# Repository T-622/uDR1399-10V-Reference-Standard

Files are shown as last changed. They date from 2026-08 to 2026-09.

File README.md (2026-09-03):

# uDR1399-10V-Reference-Standard

The second revision of the ADR1399 portable bench standard for stable voltage outputs. 

# **Background:**

After the previous version of my ADR1399 standard, the stability left something to be desired. As a result, this version incorporates bootstrapping, an output transistor, and adjustable current limiting. Furthermore, additional ESD protection has been added to the output. The output now incorporates an LT5400 resistor network for gain setting, and as such, is expected to be very stable for the precision gain stage. Two resistors can be used to increase or decrease the gain; although I was not fully after +10.00000V, and wished to have a stable reference first.

Trimming will always be required, as all ADR1399 samples I have recieved in recent times are not close to 7.05V, and usually 6.90V or 6.93V. Care must be taken to use as low temperature coeffecient resistors as possible for trimming, as they introduce extra instabilities to the gain stage.

# **Design:**

## **Schematic**
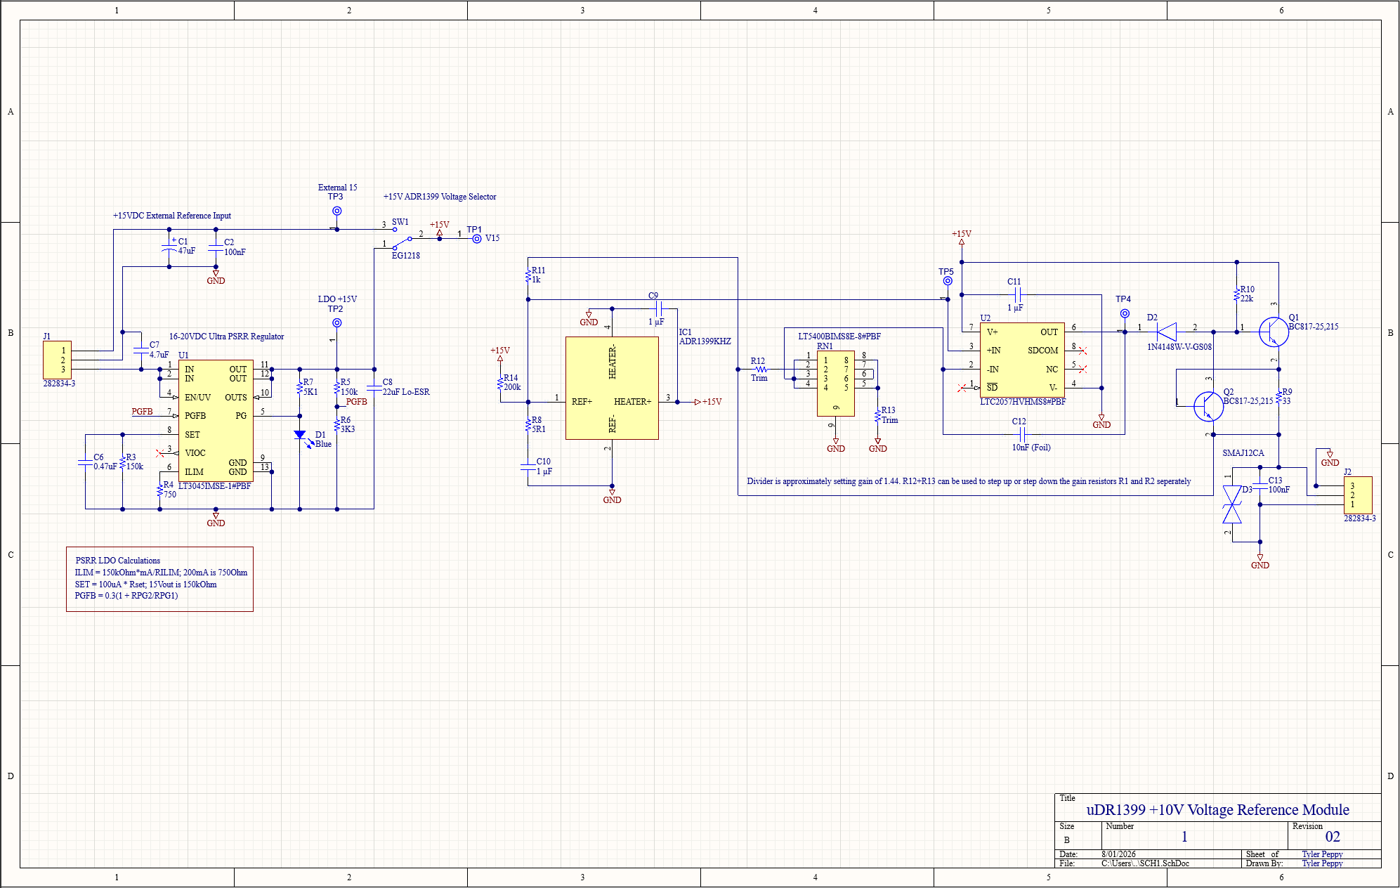
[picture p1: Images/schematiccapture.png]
DesignSchematic


## **Board Layout**

### **2D Board Multilayer:**
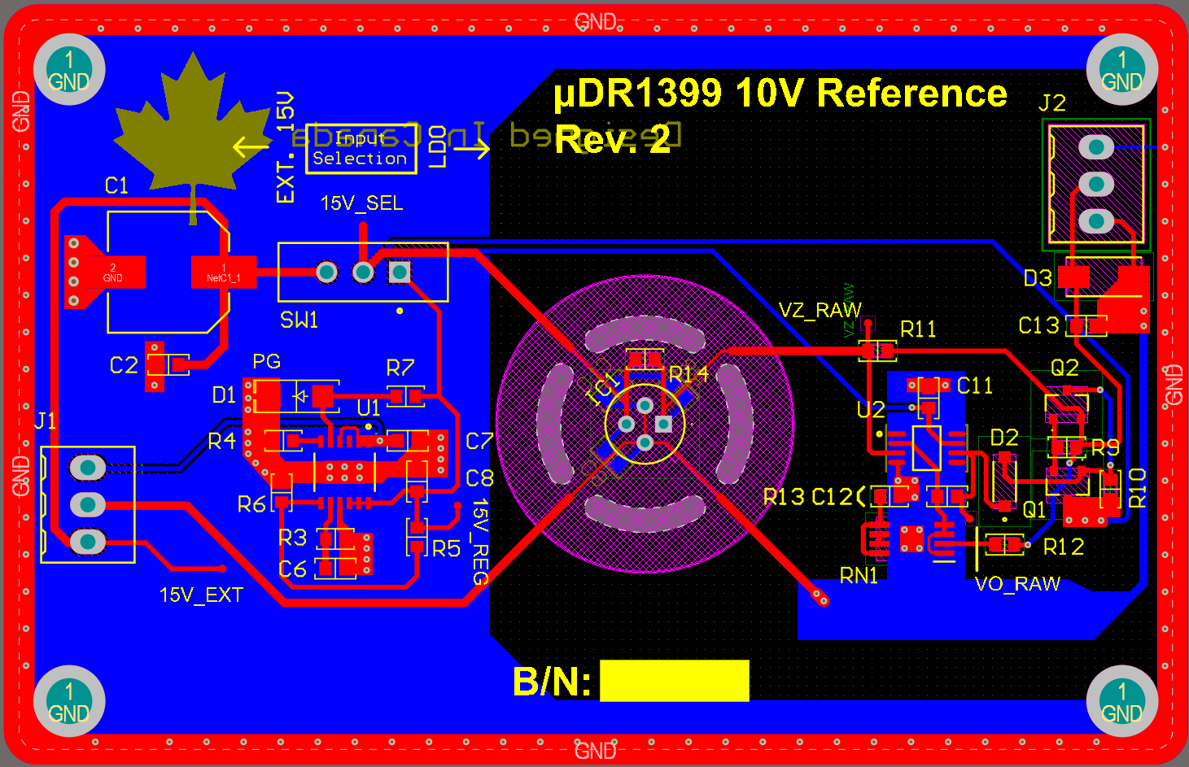
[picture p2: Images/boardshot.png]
Board Layout


### **3D Board Renderings**
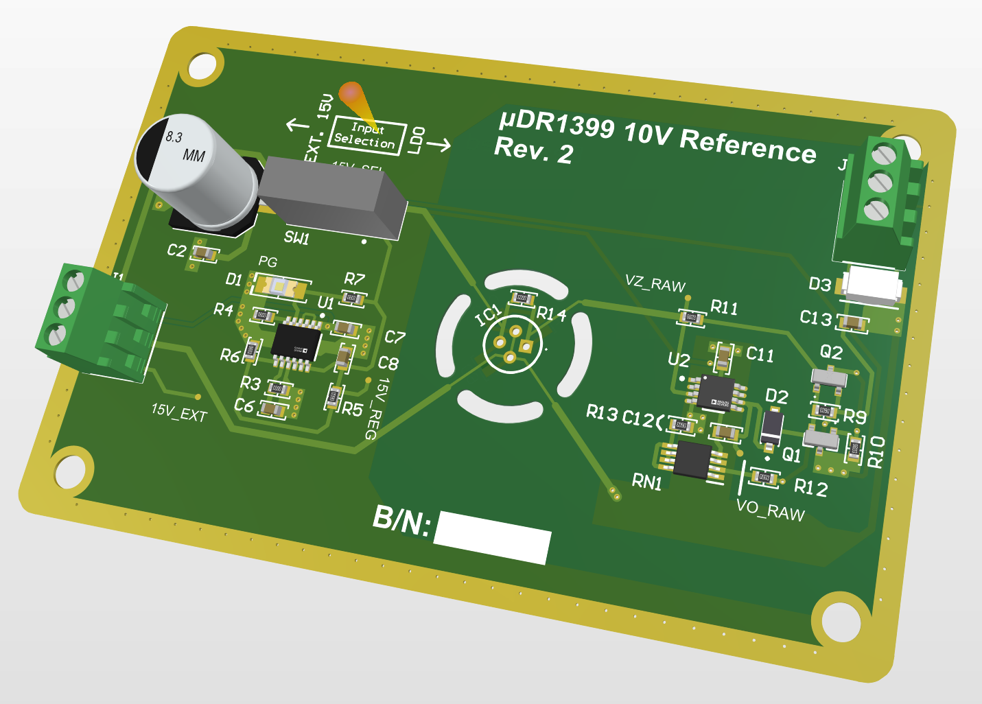
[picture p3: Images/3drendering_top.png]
3D Board Rendering

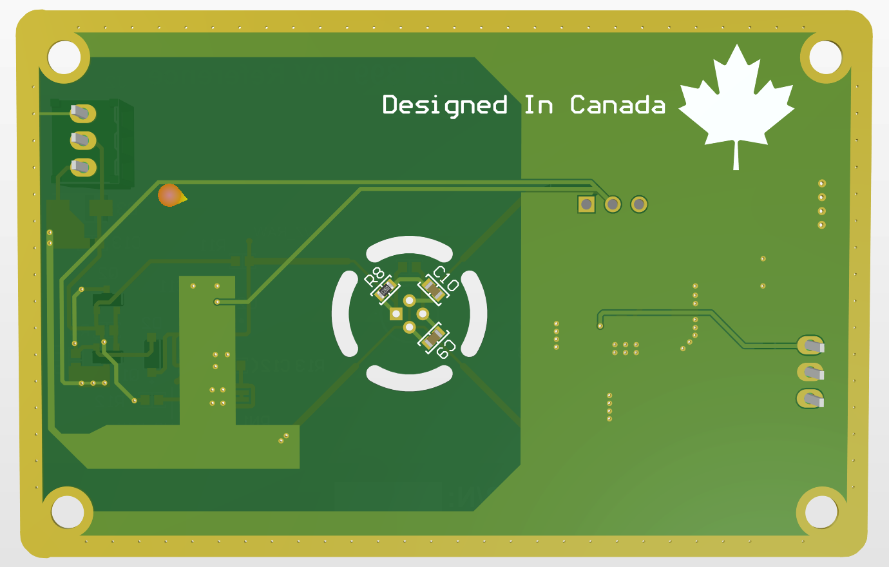
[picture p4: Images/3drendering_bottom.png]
3D Board Rendering


# **Design Notes:**
## **1 - Power Supply:**
Much has stayed from the previous design's power supply (See: [uDR1399 Rev01](https://github.com/T-622/ADR1399-10V-Bench-Standard/tree/main)). The LT3045 is a very good regulator when used properly. One issue I encountered often with the design is that hotplugging power supplies at ~18V with the L, C, and R of the power cables can cause transients large enough to exceed the absolute +22V maximum for the LT3045's inputs. This issue can be resolved through a soft-start circuit using an RC circuit to charge the gate of a p-channel FET, or an appropriate TVS diode. I have not placed these in the design, as my power supply ramps without ringing, and 2x 9V batteries seem to work reasonably well. 

The board's manual power mux is located in the top left corner, and can select from an external 15V regulated supply, or an unregulated 16-20V input fed to the LDO. Optionally, you can use an SPDT switch to externally control the mux. The PG indicator will light up whenever the +15V output is ready from the LDO, regardless if it is being used or not.

## **2 - Island Redesign**
The isolation island was redesigned to use 4 points of contact rather than the previous single tongue design. The previous design would droop under very low force, and cause odd voltage drops. The traces now neck down from 20mil to 10mil to reduce the thermal mass coming out of the island.

## **3 - Gain Stage**
The gain stage was redesigned to use the bootstrapped Zener scheme. As a result, the 3mA zener current will be much more stable against supply fluctuations. Lots of examples are available on the EEVBlog forums using this scheme. An additional 200kOhm resistor was used to assist with startup current for the reference as well. It doesn't seem to cause a different output behavior stuffed or not. It may be left off.

Additionally, the non-inverting amplifier gain resistors are now set by an LT5400 resistor network. The match on these for the B grade parts is 0.025%, with a 0.2ppm/c matching coeffecient. These are configured in a 2K + 4.5K stage, for a gain of 1.44v/v. Two additional trim resistors may be used if required.

## **4 - Output**
I added an ESD diode to the output to prevent damage through mishandling. The output consists of a transistor and a current limit. Currently the 33 ohm set resistor provides a maximum of 10mA. The output features the ~10V output, and the chassis ground, and the sense ground. Either can be chosen for experimentation purposes.

# **Assembly:**
Boards were ordered from JLCPCB using the ENIG-RoHS finish for better board flatness, minimising component lead stresses. A solder stencil was also added for more repeatability while assembling the boards, and better temperature control compared to using an iron. 

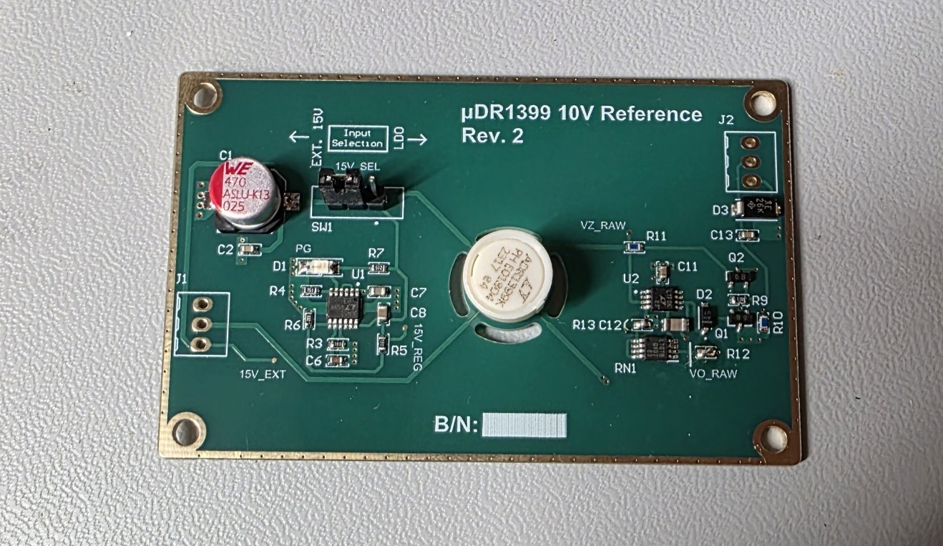
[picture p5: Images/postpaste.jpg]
Assembly


Assembly was done with ChipQuik [SMD291AXT4-T4 Leaded Solder Paste](https://www.digikey.ca/en/products/detail/chip-quik-inc/SMD291AXT4/8543521) and using a cheap hotplate at 235 degrees C. Note that these boards are NOT certified as lead free for obvious reasons. Leaded solder has a lower melting point, and is signficantly better for component stresses according to numerous voltnuts. Bismuth solder paste could be used, but it provides very little mechanical strength.

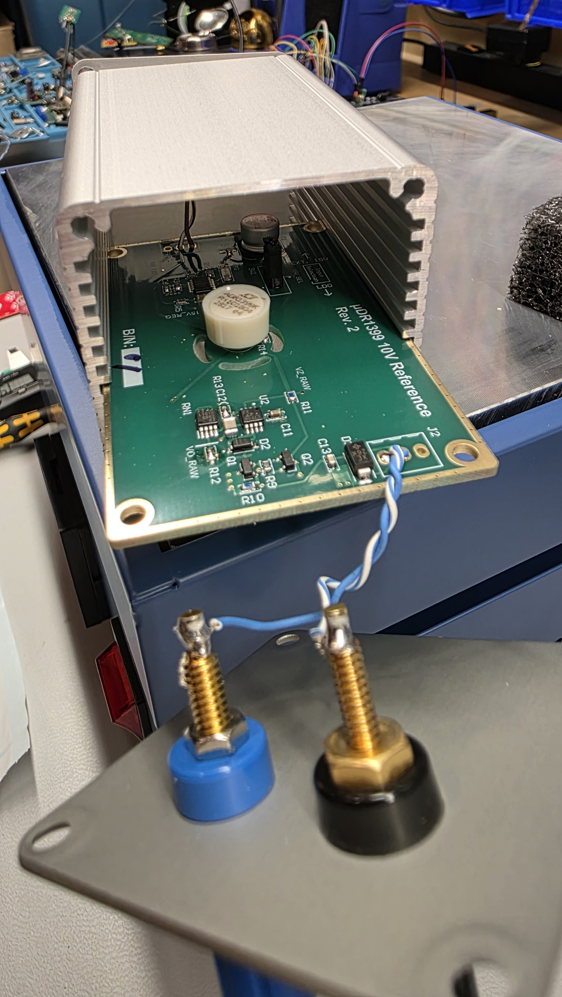
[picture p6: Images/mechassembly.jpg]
Mechanical Case Assembly


The case uses a Hammond Manufacturing 1455CS801 80mmx54mm case with internally ribbed board supports. This is the most simple solution for most users, and uses the top and bottom layer edge plating to ground the enclosure, without directly attaching it to the output sense ground. For binding posts, the output terminals should be assembled with solid copper twisted pair ethernet cable (Cabling can be found for cheap or out of many cables), coupled with Pomona 3770 gold-plated tellurium copper posts.

For output sensing, it is helpful to use 19.05mm spaced posts, as they will fit BNC-Banana for shielded sense leads. The input connectors do not require such posts, and can be used freely. Foam Caps out of closed-cell foam are ideal to attach onto the board to avoid air currents around the ADR1399, but 3D printed ones can be created from the board's .STEP model provided in this repository.

# **Stability Testing**

Before powering ON, PLEASE READ Design Note 1 - Power supply. This will help understanding potential input voltage damage risks associated with connections.

Stability testing was conducted after 72H on unit 1 of 3. The following results were obtained by my Keithley DMM6500 6-1/2 digit multimeter:

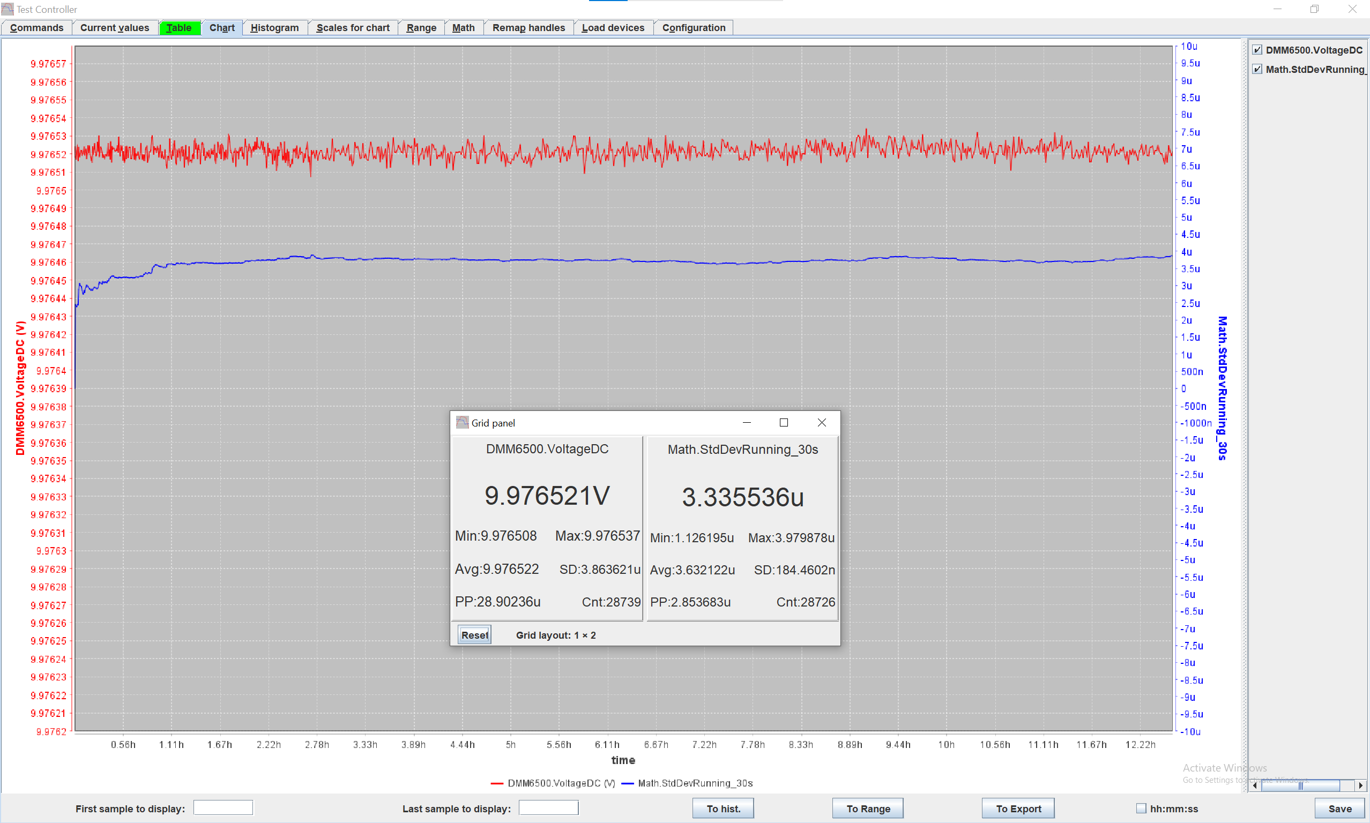
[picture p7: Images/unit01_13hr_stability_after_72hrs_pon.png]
Initial Stability


Using 10NPLC, 10 sample Repeating filter, 10GOhm InZ, AZ On, test controller works well to collect large amounts of stability data. I will update with temeperature data once I get a chance. The DMM6500 is relatively noisy, thus the STD-Dev is calculated over 1799 samples for averaging. 3.33uV STD-Dev is signficantly better than the Rev01 board, which obtained only about 8uV. 

# **Long-Term Stability and Noise Tests**

The unit being tested is approaching 900Hrs of power on / burn in at this point. An MY64 (May 2024 Cal) Keysight 34465A is further being used to aid in stability testing. As in [this](https://www.eevblog.com/forum/testgear/bench-dmm-stability-comparisons-with-testcontroller/125/) extensive thread on the EEVBlog Forums, the Keithley DMM6500 is well suited in being an overall very temperature stable meter with a great interface, but its' internal reference and acquisition mechanism is creating quite a lot of noise. A Keysight 34465A is significantly lower in noise when used in 100PLC to compare to a Keithley's 10PLC + 10x Repeating filter. 

Noise performance was evaluated through 6 tests, split into 100PLC and 10PLC + 10x Smoothing Average filter categories. Each test was averaged over a 5 trial window. Increments of 2min, 5min, and 10min were used to obtain the best representation of the uDR1399's output noise across various time intervals. 

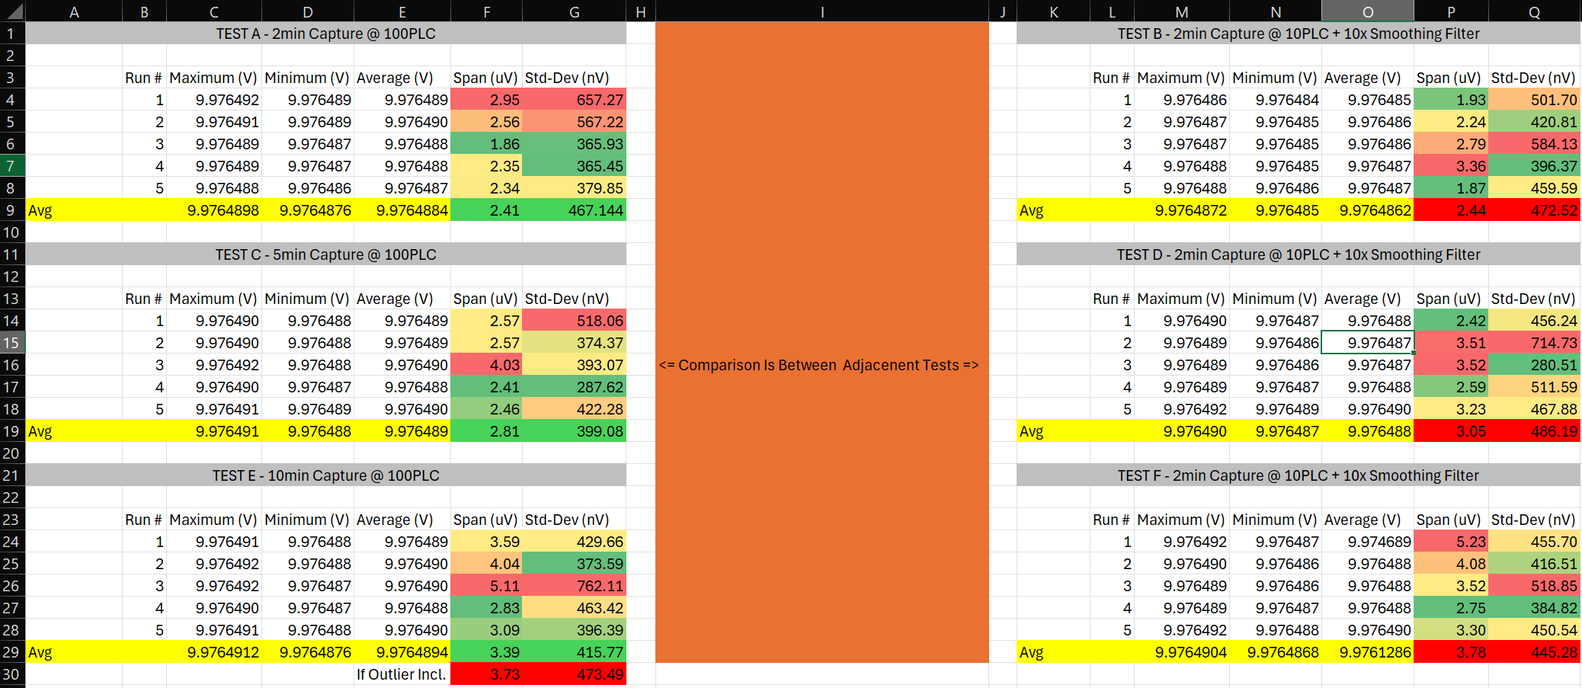
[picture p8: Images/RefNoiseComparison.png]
Reference Noise Comparison Tests


Overall, the uDR1399's output noise appears to be best at 5min sampling @ 100PLC, at approximately 399.08nV. This has been shown on the earlier EEVBlog forum thread to be lower and more temperature-independent than similar modules such as the VREF10. Further testing will be performed on the CircuitValley Ten399 3V1, which utlizes the ADI ADR1399.

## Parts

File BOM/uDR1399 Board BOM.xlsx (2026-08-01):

Country of Origin may be different at time of shipment.
The HTSUS and ECCN information shown is for informational purposes only and is not a representation or warranty as to the accuracy or reliability of these classifications. All information is provided "as is" and is subject to change without notice. Any use made of the information provided is without recourse to Digi-Key and at the user's risk.
Index | Manufacturer Part Number | Manufacturer Name | Description | Lead Time | Availability | Stock Status | Attrition % | Requested Quantity 1 | Pack Quantity 1 | Pack Type 1 | Digi-Key Part Number 1 | Unit Price 1 | Extended Price 1 | Minimum Order Quantity 1 | Requested Quantity 2 | Pack Quantity 2 | Pack Type 2 | Digi-Key Part Number 2 | Unit Price 2 | Extended Price 2 | Minimum Order Quantity 2 | Requested Quantity 3 | Pack Quantity 3 | Pack Type 3 | Digi-Key Part Number 3 | Unit Price 3 | Extended Price 3 | Minimum Order Quantity 3 | Customer Reference | Requested Part Number | Lead Weeks | Datasheet | Reference Designator | US Import Tariff | Note | Part Status | RoHS Status | REACH Status | Moisture Sensitivity Level (MSL) | ECCN | HTSUS | Country of Origin | Environmental Information | Original Part numbers | Unit of Measure | Image | Product Notes
1 | 865090449007 | Würth Elektronik | CAP ALUM 47UF 20% 25V SMD |  | 274 | In Stock |  | 1 | 1 | Cut Tape (CT) | 732-8369-1-ND | 0.76000 | $0.76 | 1 | 1 | 1 | Cut Tape (CT) | 732-8369-1-ND | 0.76000 | $0.76 | 1 | 1 | 1 | Cut Tape (CT) | 732-8369-1-ND | 0.76000 | $0.76 | 1 |  | 732-8369-1-ND | 24 | https://www.we-online.com/components/products/datasheet/865090449007.pdf |  | N/A |  | Active | ROHS3 Compliant | REACH Unaffected | 1 (Unlimited) | EAR99 | 8532.22.0020 | China | https://mm.digikey.com/Volume0/opasdata/d220001/medias/docus/744/Certificate_of_Compliance_ROHS.pdf | 732-8369-1-ND | Each | https://mm.digikey.com/Volume0/opasdata/d220001/derivates/6/002/315/945/MFG_WCAP-ASLU_web%28640x640%29.jpg
2 | C0603C104K5RACTU | KEMET | CAP CER 0.1UF 50V X7R 0603 |  | 6,385,741 | In Stock |  | 2 | 2 | Cut Tape (CT) | 399-C0603C104K5RACTUCT-ND | 0.19000 | $0.38 | 1 | 2 | 2 | Cut Tape (CT) | 399-C0603C104K5RACTUCT-ND | 0.19000 | $0.38 | 1 | 2 | 2 | Cut Tape (CT) | 399-C0603C104K5RACTUCT-ND | 0.19000 | $0.38 | 1 |  | 399-C0603C104K5RACTUCT-ND | 12 | https://yageogroup.com/content/datasheet/asset/file/KEM_C1002_X7R_SMD |  | N/A |  | Active | ROHS3 Compliant | REACH Unaffected | 1 (Unlimited) | EAR99 | 8532.24.0020 | China |  | 399-C0603C104K5RACTUCT-ND | Each | https://mm.digikey.com/Volume0/opasdata/d220001/derivates/6/003/121/213/cut-tape-render_web%28640x640%29.jpg
3 | C1608X5R1C474K080AA | TDK | CAP CER 0.47UF 16V X5R 0603 |  | 32,533 | In Stock |  | 4 | 4 | Cut Tape (CT) | 445-5152-1-ND | 0.15000 | $0.60 | 1 | 1 | 1 | Cut Tape (CT) | 445-5152-1-ND | 0.15000 | $0.15 | 1 | 1 | 1 | Cut Tape (CT) | 445-5152-1-ND | 0.15000 | $0.15 | 1 |  | 445-5152-1-ND | 12 | https://product.tdk.com/system/files/dam/doc/product/capacitor/ceramic/mlcc/catalog/mlcc_commercial_general_en.pdf |  | N/A |  | Active | ROHS3 Compliant | REACH Unaffected | 1 (Unlimited) | EAR99 | 8532.24.0020 | Japan | https://product.tdk.com/system/files/dam/doc/product/capacitor/ceramic/mlcc/rohs/mlccrohs_commercial_general_en.pdf|https://product.tdk.com/en/environment/index.html | 445-5152-1-ND | Each | https://mm.digikey.com/Volume0/opasdata/d220001/derivates/6/002/622/019/C%20Series%200603%281608%20Metric%29%209_web%28640x640%29.jpg
4 | RT0603BRC07150KL | YAGEO | RES SMD 150K OHM 0.1% 1/10W 0603 |  | 4,994 | In Stock |  | 6 | 6 | Cut Tape (CT) | 13-RT0603BRC07150KLCT-ND | 0.43000 | $2.58 | 1 | 2 | 2 | Cut Tape (CT) | 13-RT0603BRC07150KLCT-ND | 0.43000 | $0.86 | 1 | 2 | 2 | Cut Tape (CT) | 13-RT0603BRC07150KLCT-ND | 0.43000 | $0.86 | 1 |  | 13-RT0603BRC07150KLCT-ND | 20 | https://yageogroup.com/content/datasheet/asset/file/PYU-RT_1-TO-0-01_ROHS_L |  | N/A |  | Active | ROHS3 Compliant | REACH Unaffected | 1 (Unlimited) | EAR99 | 8533.21.0030 | Taiwan |  | 13-RT0603BRC07150KLCT-ND | Each | https://mm.digikey.com/Volume0/opasdata/d220001/medias/images/4839/RT-Series-Chip-Resistor.jpg
5 | ERA-3APB751V | Panasonic Industry | RES SMD 750 OHM 0.1% 1/10W 0603 |  | 607 | In Stock |  | 7 | 7 | Cut Tape (CT) | P750AYCT-ND | 0.43000 | $3.01 | 1 | 1 | 1 | Cut Tape (CT) | P750AYCT-ND | 0.43000 | $0.43 | 1 | 1 | 1 | Cut Tape (CT) | P750AYCT-ND | 0.43000 | $0.43 | 1 |  | P750AYCT-ND | 33 | https://industrial.panasonic.com/cdbs/www-data/pdf/RDM0000/AOA0000C307.pdf |  | N/A |  | Active | ROHS3 Compliant | REACH Unaffected | 1 (Unlimited) | EAR99 | 8533.21.0030 | Japan | https://industrial.panasonic.com/cdbs/www-cgi/auto-publishing.cgi?type=ROSU&region=WW&layer=4&cd=AOA0026 | P750AYCT-ND | Each | https://mm.digikey.com/Volume0/opasdata/d220001/medias/images/2391/10-0603%20Resistor.jpg
6 | ERA-3ARW512V | Panasonic Industry | RES SMD 5.1KOHM 0.05% 1/10W 0603 |  | 6,524 | In Stock |  | 8 | 8 | Cut Tape (CT) | P5.1KBECT-ND | 0.79000 | $6.32 | 1 | 1 | 1 | Cut Tape (CT) | P5.1KBECT-ND | 0.79000 | $0.79 | 1 | 1 | 1 | Cut Tape (CT) | P5.1KBECT-ND | 0.79000 | $0.79 | 1 |  | P5.1KBECT-ND | 33 | https://industrial.panasonic.com/cdbs/www-data/pdf/RDM0000/AOA0000C307.pdf |  | N/A |  | Active | ROHS3 Compliant | REACH Unaffected | 1 (Unlimited) | EAR99 | 8533.21.0030 | Japan | https://industrial.panasonic.com/cdbs/www-cgi/auto-publishing.cgi?type=ROSU&region=WW&layer=4&cd=AOA0026 | P5.1KBECT-ND | Each | https://mm.digikey.com/Volume0/opasdata/d220001/medias/images/2391/10-0603%20Resistor.jpg
7 | ERA-3ARB332V | Panasonic Industry | RES SMD 3.3K OHM 0.1% 1/10W 0603 |  | 938 | In Stock |  | 9 | 9 | Cut Tape (CT) | P3.3KBDCT-ND | 0.63000 | $5.67 | 1 | 1 | 1 | Cut Tape (CT) | P3.3KBDCT-ND | 0.63000 | $0.63 | 1 | 1 | 1 | Cut Tape (CT) | P3.3KBDCT-ND | 0.63000 | $0.63 | 1 |  | P3.3KBDCT-ND | 33 | https://industrial.panasonic.com/cdbs/www-data/pdf/RDM0000/AOA0000C307.pdf |  | N/A |  | Active | ROHS3 Compliant | REACH Unaffected | 1 (Unlimited) | EAR99 | 8533.21.0030 | Japan | https://industrial.panasonic.com/cdbs/www-cgi/auto-publishing.cgi?type=ROSU&region=WW&layer=4&cd=AOA0026 | P3.3KBDCT-ND | Each | https://mm.digikey.com/Volume0/opasdata/d220001/medias/images/2391/10-0603%20Resistor.jpg
8 | RG1608N-204-W-T1 | Susumu | RES SMD 200KOHM 0.05% 1/10W 0603 |  | 37,801 | In Stock |  | 10 | 10 | Cut Tape (CT) | RG16N200KWCT-ND | 0.83900 | $8.39 | 1 | 1 | 1 | Cut Tape (CT) | RG16N200KWCT-ND | 1.02000 | $1.02 | 1 | 1 | 1 | Cut Tape (CT) | RG16N200KWCT-ND | 1.02000 | $1.02 | 1 |  | RG16N200KWCT-ND | 22 | https://www.susumu.co.jp/dl/?filename=n_catalog_partition01_en.pdf&type=application/pdf |  | N/A |  | Active | ROHS3 Compliant | REACH Unaffected | 1 (Unlimited) | EAR99 | 8533.21.0030 | Japan | https://www.susumu.co.jp/common/pdf/Certificate%20of%20EU%20RoHS%20compliance.pdf | RG16N200KWCT-ND | Each | https://mm.digikey.com/Volume0/opasdata/d220001/derivates/6/003/243/936/MFG_408_RG_0603_web%28640x640%29.jpg
9 | RNCF0603DTE5R10 | Stackpole Electronics Inc | RES SMD 5.1 OHM 0.5% 1/10W 0603 |  | 4,426 | In Stock |  | 11 | 11 | Cut Tape (CT) | 738-RNCF0603DTE5R10CT-ND | 0.04600 | $0.51 | 1 | 1 | 1 | Cut Tape (CT) | 738-RNCF0603DTE5R10CT-ND | 0.16000 | $0.16 | 1 | 1 | 1 | Cut Tape (CT) | 738-RNCF0603DTE5R10CT-ND | 0.16000 | $0.16 | 1 |  | 738-RNCF0603DTE5R10CT-ND | 18 | https://www.seielect.com/catalog/SEI-RNCF.pdf |  | N/A |  | Active | ROHS3 Compliant | REACH Unaffected | 1 (Unlimited) | EAR99 | 8533.21.0030 | Taiwan | https://www.seielect.com/catalog/SEI-RoHS_Compliance_Status.pdf|https://www.seielect.com/catalog/reach.pdf|https://www.seielect.com/catalog/sei-coc%20prop%2065.pdf | 738-RNCF0603DTE5R10CT-ND | Each | https://mm.digikey.com/Volume0/opasdata/d220001/derivates/6/003/238/576/MFG_RNCF_series_web%28640x640%29.jpg
10 | TNPU060322K0BZEN00 | Vishay Dale | RES SMD 22K OHM 0.1% 1/10W 0603 |  | 1,261 | In Stock |  | 12 | 12 | Cut Tape (CT) | 541-TNPU060322K0BZEN00CT-ND | 2.60300 | $31.24 | 1 | 1 | 1 | Cut Tape (CT) | 541-TNPU060322K0BZEN00CT-ND | 3.14000 | $3.14 | 1 | 1 | 1 | Cut Tape (CT) | 541-TNPU060322K0BZEN00CT-ND | 3.14000 | $3.14 | 1 |  | 541-TNPU060322K0BZEN00CT-ND | 13 | https://www.vishay.com/docs/28779/tnpue3.pdf |  | N/A |  | Active | ROHS3 Compliant | REACH Unaffected | 1 (Unlimited) | EAR99 | 8533.21.0030 | Germany |  | 541-TNPU060322K0BZEN00CT-ND | Each | https://mm.digikey.com/Volume0/opasdata/d220001/medias/images/3648/MFG_TNPU0603.jpg
11 | RT0603BRC0733RL | YAGEO | RES SMD 33 OHM 0.1% 1/10W 0603 |  | 3,048 | In Stock |  | 13 | 13 | Cut Tape (CT) | 13-RT0603BRC0733RLCT-ND | 0.33300 | $4.33 | 1 | 1 | 1 | Cut Tape (CT) | 13-RT0603BRC0733RLCT-ND | 0.40000 | $0.40 | 1 | 1 | 1 | Cut Tape (CT) | 13-RT0603BRC0733RLCT-ND | 0.40000 | $0.40 | 1 |  | 13-RT0603BRC0733RLCT-ND | 20 | https://yageogroup.com/content/datasheet/asset/file/PYU-RT_1-TO-0-01_ROHS_L |  | N/A |  | Active | ROHS3 Compliant | REACH Unaffected | 1 (Unlimited) | EAR99 | 8533.21.0030 | Taiwan |  | 13-RT0603BRC0733RLCT-ND | Each | https://mm.digikey.com/Volume0/opasdata/d220001/medias/images/4839/RT-Series-Chip-Resistor.jpg
12 | TNPU06031K00BZEA00 | Vishay Dale | RES 1 KOHM 0.1% 1/10W 0603 |  | 4,844 | In Stock |  | 14 | 14 | Cut Tape (CT) | 541-4650-1-ND | 1.96600 | $27.52 | 1 | 1 | 1 | Cut Tape (CT) | 541-4650-1-ND | 2.36000 | $2.36 | 1 | 1 | 1 | Cut Tape (CT) | 541-4650-1-ND | 2.36000 | $2.36 | 1 |  | 541-4650-1-ND | 13 | https://www.vishay.com/docs/28779/tnpue3.pdf |  | N/A |  | Active | ROHS3 Compliant | REACH Unaffected | 1 (Unlimited) | EAR99 | 8533.21.0030 | Germany |  | 541-4650-1-ND | Each | https://mm.digikey.com/Volume0/opasdata/d220001/medias/images/3648/MFG_TNPU0603.jpg
13 | CL10A105KO8NNNC | Samsung Electro-Mechanics | CAP CER 1UF 16V X5R 0603 |  | 80,732 | In Stock |  | 15 | 15 | Cut Tape (CT) | 1276-1034-1-ND | 0.06800 | $1.02 | 1 | 3 | 3 | Cut Tape (CT) | 1276-1034-1-ND | 0.16000 | $0.48 | 1 | 3 | 3 | Cut Tape (CT) | 1276-1034-1-ND | 0.16000 | $0.48 | 1 |  | 1276-1034-1-ND | 49 | https://mm.digikey.com/Volume0/opasdata/d220001/medias/docus/609/CL10A105KO8NNNC_Spec.pdf |  | N/A |  | Active | ROHS3 Compliant | REACH Unaffected | 1 (Unlimited) | EAR99 | 8532.24.0020 | Philippines | https://www.samsungsem.com/files/fileDown.do?key=ed1dfdfa-645e-4252-b707-17f9b1502dd1|https://www.samsungsem.com/global/support/certificate/product-stewardship.do | 1276-1034-1-ND | Each | https://mm.digikey.com/Volume0/opasdata/d220001/medias/images/2537/Ceramic-Capacitor-CL-Series.jpg
14 | 1N4148W-E3-08 | Vishay General Semiconductor - Diodes Division | DIODE STANDARD 75V 150MA SOD123 |  | 48,652 | In Stock |  | 17 | 17 | Cut Tape (CT) | 1N4148W-E3-08CT-ND | 0.35300 | $6.00 | 1 | 1 | 1 | Cut Tape (CT) | 1N4148W-E3-08CT-ND | 0.58000 | $0.58 | 1 | 1 | 1 | Cut Tape (CT) | 1N4148W-E3-08CT-ND | 0.58000 | $0.58 | 1 |  | 1N4148W-E3-08CT-ND | 47 | https://www.vishay.com/docs/86356/1n4148w.pdf |  | N/A |  | Active | ROHS3 Compliant | REACH Unaffected | 1 (Unlimited) | EAR99 | 8541.10.0070 | China |  | 1N4148W-E3-08CT-ND | Each | https://mm.digikey.com/Volume0/opasdata/d220001/medias/images/5789/112%7ESOD123%7E%7E2-View-2.jpg
15 | BC817-25 | EVVO | TRANS NPN 45V 0.5A SOT-23 |  | 973 | In Stock |  | 18 | 18 | Cut Tape (CT) | 5272-BC817-25CT-ND | 0.27100 | $4.88 | 1 | 2 | 2 | Cut Tape (CT) | 5272-BC817-25CT-ND | 0.44000 | $0.88 | 1 | 2 | 2 | Cut Tape (CT) | 5272-BC817-25CT-ND | 0.44000 | $0.88 | 1 |  | 5272-BC817-25CT-ND | 3 | https://mm.digikey.com/Volume0/opasdata/d220001/medias/docus/7158/5272_BC817-25.pdf |  | N/A |  | Active | ROHS3 Compliant | REACH Unaffected | 1 (Unlimited) | EAR99 | 8541.21.0075 | China |  | 5272-BC817-25CT-ND | Each | https://mm.digikey.com/Volume0/opasdata/d220001/derivates/6/003/235/272/MFG_5272%7ESOT23-3%7E%7E3_web%28640x640%29.jpg
16 | SMAJ12CA-E3/5A | Vishay General Semiconductor - Diodes Division | TVS DIODE 12VWM 19.9VC DO214AC |  | 4,664 | In Stock |  | 19 | 19 | Cut Tape (CT) | SMAJ12CA-E3/5AGICT-ND | 0.51800 | $9.84 | 1 | 1 | 1 | Cut Tape (CT) | SMAJ12CA-E3/5AGICT-ND | 0.83000 | $0.83 | 1 | 1 | 1 | Cut Tape (CT) | SMAJ12CA-E3/5AGICT-ND | 0.83000 | $0.83 | 1 |  | SMAJ12CA-E3/5AGICT-ND | 28 | https://www.vishay.com/docs/88390/smaj50a.pdf |  | N/A |  | Active | ROHS3 Compliant | REACH Unaffected | 1 (Unlimited) | EAR99 | 8541.10.0080 | Taiwan |  | SMAJ12CA-E3/5AGICT-ND | Each
17 | LT3045IMSE-1#PBF | Analog Devices Inc. | IC REG LIN POS ADJ 500MA 12MSOP |  | 3,196 | In Stock |  | 20 | 20 | Tube | 505-LT3045IMSE-1#PBF-ND | 12.91000 | $258.20 | 1 | 1 | 1 | Tube | 505-LT3045IMSE-1#PBF-ND | 16.55000 | $16.55 | 1 | 1 | 1 | Tube | 505-LT3045IMSE-1#PBF-ND | 16.55000 | $16.55 | 1 |  | 505-LT3045IMSE-1#PBF-ND | 19 | https://www.analog.com/media/en/technical-documentation/data-sheets/30451fa.pdf |  | N/A |  | Active | ROHS3 Compliant | REACH Unaffected | 1 (Unlimited) | EAR99 | 8542.39.0070 | Thailand | https://www.analog.com/media/en/material-declaration/LT3045IMSE-1%23PBF.PDF | 505-LT3045IMSE-1#PBF-ND | Each | https://mm.digikey.com/Volume0/opasdata/d220001/medias/images/4830/505%7E05-08-1666%7EMSE%7E12-Pad-View.JPG
18 | ADR1399KHZ | Analog Devices Inc. | IC VREF SHUNT 7.05V 0.05% TO46-4 |  | 1,263 | In Stock |  | 21 | 21 | Tube | 505-ADR1399KHZ-ND | 32.74350 | $687.61 | 1 | 1 | 1 | Tube | 505-ADR1399KHZ-ND | 42.69000 | $42.69 | 1 | 1 | 1 | Tube | 505-ADR1399KHZ-ND | 42.69000 | $42.69 | 1 |  | 505-ADR1399KHZ-ND | 10 | https://www.analog.com/media/en/technical-documentation/data-sheets/adr1399.pdf |  | N/A |  | Active | ROHS3 Compliant | REACH Unaffected | 1 (Unlimited) | EAR99 | 8542.39.0090 | Philippines |  | 505-ADR1399KHZ-ND | Each | https://mm.digikey.com/Volume0/opasdata/d220001/derivates/6/003/228/004/MFG_505%7E05-08-1341%7EH%7E4_web%28640x640%29.jpg
19 | LT5400BIMS8E-8#PBF | Analog Devices Inc. | RES ARRAY 4 RES MULT OHM 8TSSOP |  | 682 | In Stock |  | 22 | 22 | Tube | LT5400BIMS8E-8#PBF-ND | 17.65700 | $388.45 | 1 | 1 | 1 | Tube | LT5400BIMS8E-8#PBF-ND | 25.16000 | $25.16 | 1 | 1 | 1 | Tube | LT5400BIMS8E-8#PBF-ND | 25.16000 | $25.16 | 1 |  | LT5400BIMS8E-8#PBF-ND | 13 | https://www.analog.com/media/en/technical-documentation/data-sheets/5400fc.pdf |  | N/A |  | Active | ROHS3 Compliant | REACH Unaffected | 1 (Unlimited) | EAR99 | 8533.21.0020 | Thailand | https://www.analog.com/media/en/material-declaration/LT5400BIMS8E-8%23PBF.PDF | LT5400BIMS8E-8#PBF-ND | Each | https://mm.digikey.com/Volume0/opasdata/d220001/derivates/6/001/124/015/505%7E05-08-1662%7EMS8E%7E8_web%28640x640%29.jpg
20 | LTC2057IMS8#PBF | Analog Devices Inc. | IC OPAMP ZERO-DRIFT 1 CIRC 8MSOP |  | 2,254 | In Stock |  | 23 | 23 | Tube | 505-LTC2057IMS8#PBF-ND | 4.97800 | $114.49 | 1 | 1 | 1 | Tube | 505-LTC2057IMS8#PBF-ND | 6.58000 | $6.58 | 1 | 1 | 1 | Tube | 505-LTC2057IMS8#PBF-ND | 6.58000 | $6.58 | 1 |  | 505-LTC2057IMS8#PBF-ND | 19 | https://www.analog.com/media/en/technical-documentation/data-sheets/2057f.pdf |  | N/A |  | Active | ROHS3 Compliant | REACH Unaffected | 1 (Unlimited) | EAR99 | 8542.33.0001 | Thailand | https://www.analog.com/media/en/material-declaration/LTC2057IMS8%23PBF.PDF | 505-LTC2057IMS8#PBF-ND | Each | https://mm.digikey.com/Volume0/opasdata/d220001/derivates/6/300/951/778/505%7E05-08-1660%7EMS8%7E8_web%28640x640%29.jpg
21 | 1455CS801 | Hammond Manufacturing | EXTRUDED ALUMINUM ENCLOSURE W/ M | 20 in stock at manufacturer warehouse as of 31-Jul-2026 | 4 | In Stock |  | 24 | 24 | Bulk | 164-1455CS801-ND | 21.21700 | $509.21 | 1 | 1 | 1 | Bulk | 164-1455CS801-ND | 27.14000 | $27.14 | 1 | 1 | 1 | Bulk | 164-1455CS801-ND | 27.14000 | $27.14 | 1 |  | 164-1455CS801-ND | 8 | https://www.hammfg.com/electronics/small-case/extruded/1455.pdf |  | N/A |  | Active | ROHS3 Compliant | REACH Unaffected | Not Applicable | EAR99 | 7612.90.1090 | Canada |  | 164-1455CS801-ND | Each | https://mm.digikey.com/Volume0/opasdata/d220001/derivates/6/003/232/509/1455CS801_web%28640x640%29.jpg | This product can be customized by the manufacturer.
22 | GMK107BBJ475KA-T | Taiyo Yuden | CAP CER 4.7UF 35V X5R 0603 |  | 26,177 | In Stock |  | 1 | 1 | Cut Tape (CT) | 587-GMK107BBJ475KA-TCT-ND | 0.68000 | $0.68 | 1 |  |  |  |  |  |  |  |  |  |  |  |  |  |  |  | 587-GMK107BBJ475KA-TTR-ND | 13 | https://mm.digikey.com/Volume0/opasdata/d220001/medias/docus/57/GMK107BBJ475KA-T_SS.pdf |  | N/A |  | Active | ROHS3 Compliant | REACH Unaffected | 1 (Unlimited) | EAR99 | 8532.24.0020 | Japan |  | 587-GMK107BBJ475KA-TTR-ND | Each | https://mm.digikey.com/Volume0/opasdata/d220001/medias/images/331/Taiyo-Yuden-0603-%281608-Metric%29.jpg
23 | CL10A226MO7JZNC | Samsung Electro-Mechanics | CAP CER 22UF 16V X5R 0603 |  | 215,193 | In Stock |  | 1 | 1 | Cut Tape (CT) | 1276-7076-1-ND | 1.22000 | $1.22 | 1 |  |  |  |  |  |  |  |  |  |  |  |  |  |  |  | 1276-7076-1-ND | 39 | https://mm.digikey.com/Volume0/opasdata/d220001/medias/docus/2139/CL10A226MO7JZNC_Spec.pdf |  | N/A |  | Active | ROHS3 Compliant | REACH Unaffected | 1 (Unlimited) | EAR99 | 8532.24.0020 | Philippines | https://www.samsungsem.com/files/fileDown.do?key=ed1dfdfa-645e-4252-b707-17f9b1502dd1|https://www.samsungsem.com/global/support/certificate/product-stewardship.do | 1276-7076-1-ND | Each | https://mm.digikey.com/Volume0/opasdata/d220001/medias/images/2537/Ceramic-Capacitor-CL-Series.jpg
24 | 150120BS75000 | Würth Elektronik | LED BLUE CLEAR 1206 SMD |  | 78,614 | In Stock |  | 1 | 1 | Cut Tape (CT) | 732-4989-1-ND | 0.36000 | $0.36 | 1 |  |  |  |  |  |  |  |  |  |  |  |  |  |  |  | 732-4989-1-ND | 13 | https://www.we-online.com/components/products/datasheet/150120BS75000.pdf |  | N/A |  | Active | ROHS3 Compliant | REACH Unaffected | 3 (168 Hours) | EAR99 | 8541.41.0000 | China | https://mm.digikey.com/Volume0/opasdata/d220001/medias/docus/744/Certificate_of_Compliance_ROHS.pdf | 732-4989-1-ND | Each | https://mm.digikey.com/Volume0/opasdata/d220001/medias/images/536/WL-SMCW-SERIES-1206-PKG.jpg
25 | ECH-U1H103JX5 | Panasonic Industry | CAP FILM 10000PF 5% 50VDC 1206 |  | 68,004 | In Stock |  | 1 | 1 | Cut Tape (CT) | PCF1340CT-ND | 0.95000 | $0.95 | 1 |  |  |  |  |  |  |  |  |  |  |  |  |  |  |  | PCF1340CT-ND | 12 | https://industrial.panasonic.com/ww/products/pt/film-cap-electroequip/models/ECHU1H103JX5 |  | N/A |  | Active | ROHS3 Compliant | REACH Unaffected | 1 (Unlimited) | EAR99 | 8532.25.0010 | Japan |  | PCF1340CT-ND | Each | https://mm.digikey.com/Volume0/opasdata/d220001/medias/images/2422/ECH-UB-UX%20SERIES%201206.jpg

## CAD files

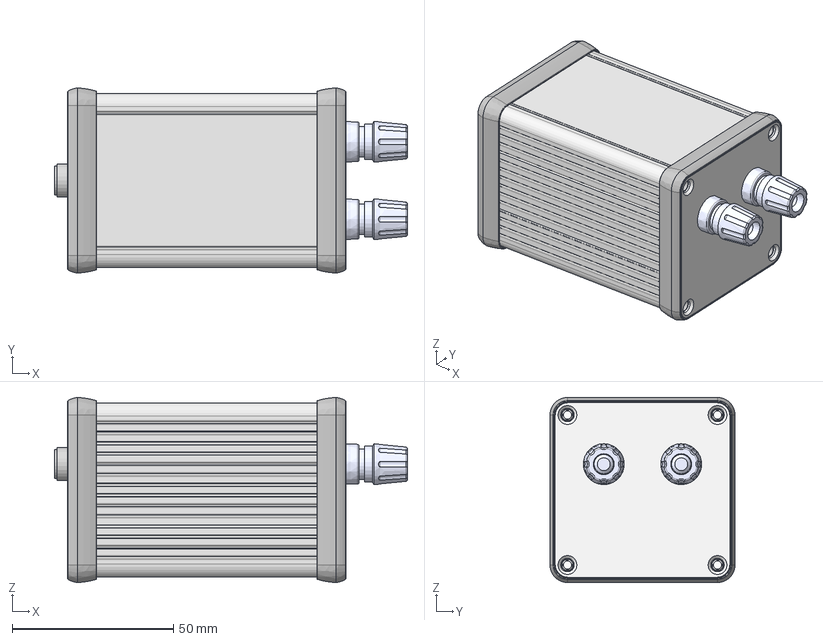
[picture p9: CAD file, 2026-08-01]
Mechanical Items/10V Reference Assembly.step
109.4 x 57.4 x 57.4 mm

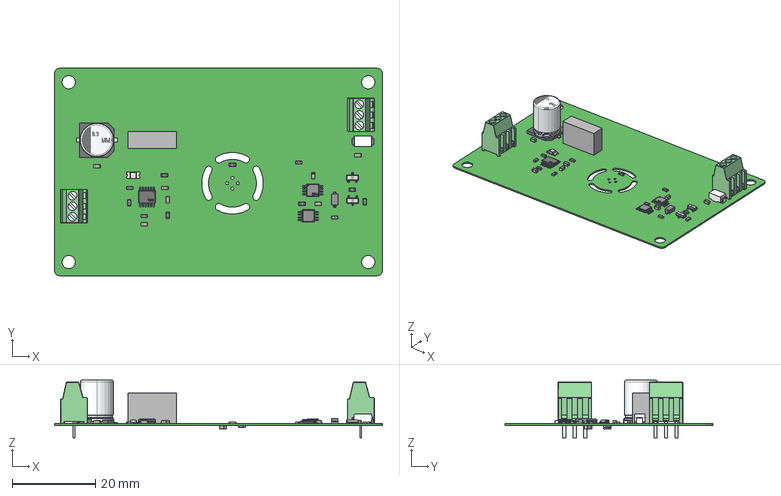
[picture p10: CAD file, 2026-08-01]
Mechanical Items/uDR1399_Board_Model.step
79.0 x 50.0 x 13.9 mm

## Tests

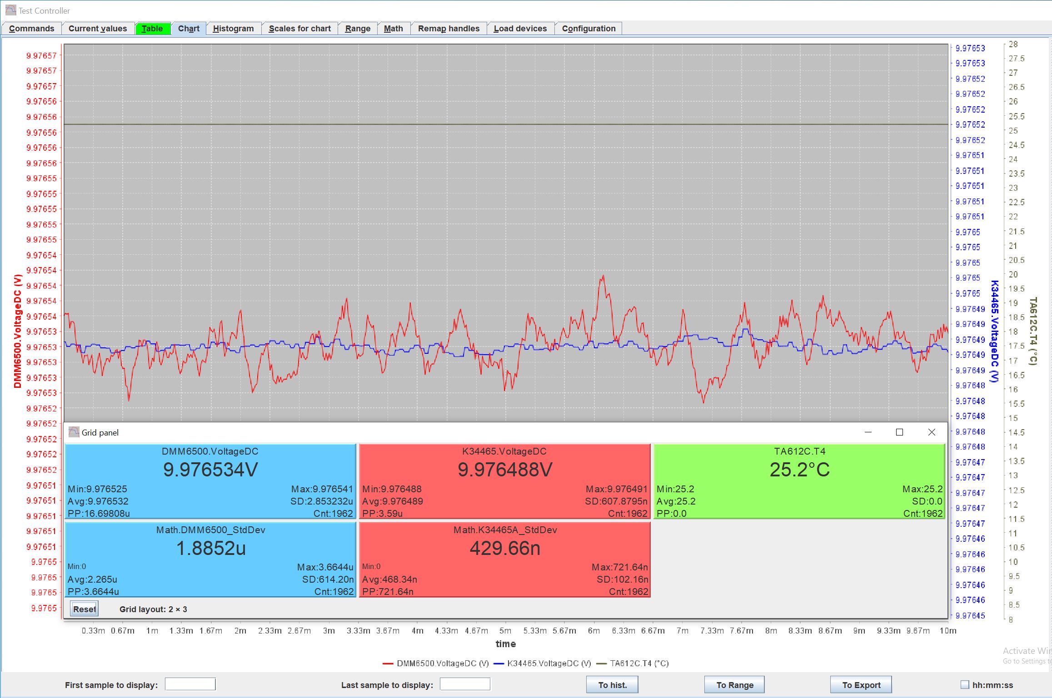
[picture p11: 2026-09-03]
uDR1399 Validation Tests/10min Tests/100PLC/100PLC_01.JPG

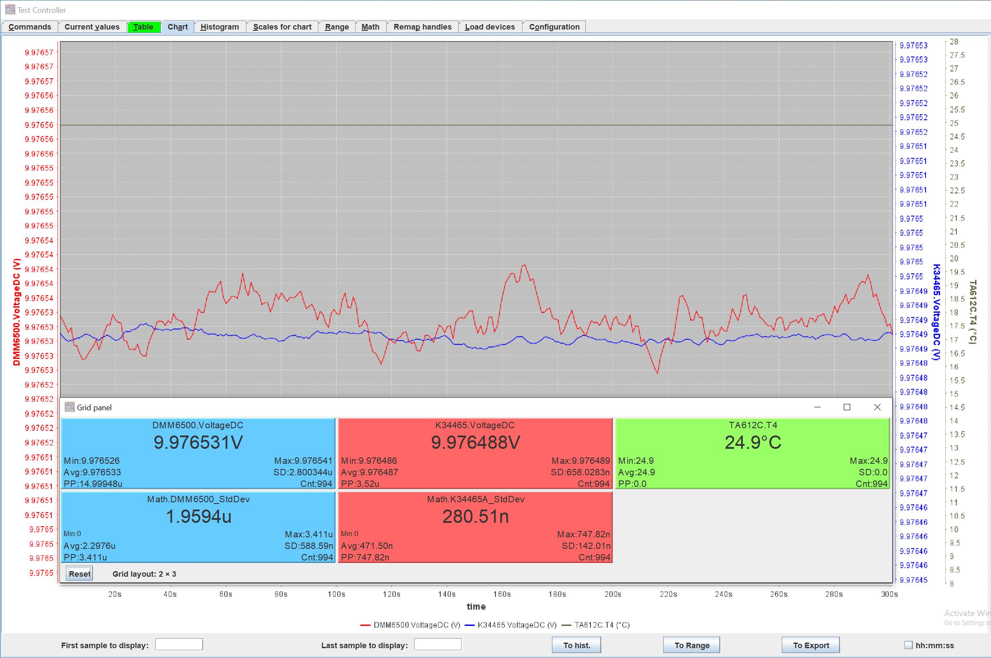
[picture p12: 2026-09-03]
uDR1399 Validation Tests/5min Tests/10PLC + 10x Smoothing/10PLC_With_Filter_03.JPG

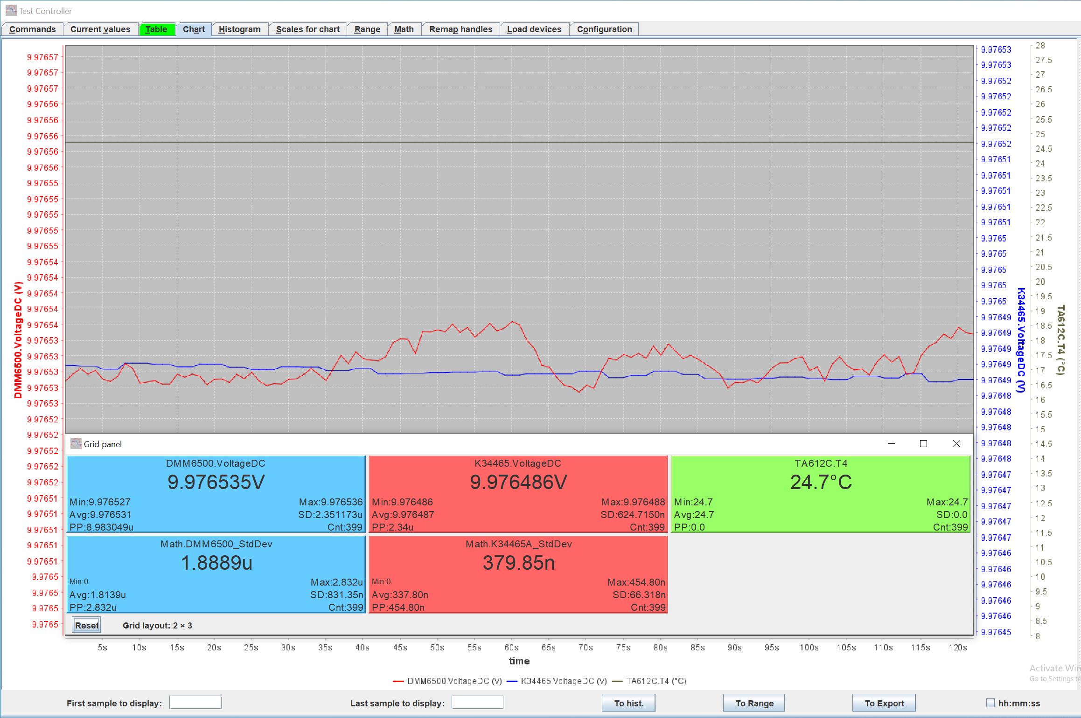
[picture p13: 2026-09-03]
uDR1399 Validation Tests/2min Tests/100PLC/100PLC_05.JPG

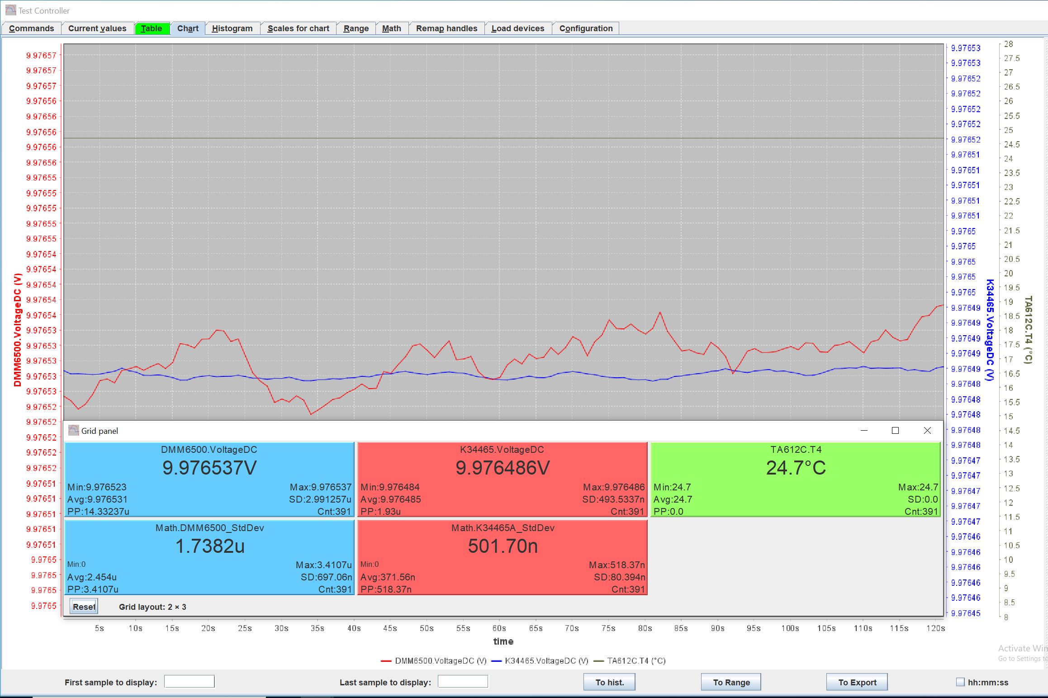
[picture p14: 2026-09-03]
uDR1399 Validation Tests/2min Tests/10PLC + 10x Smoothing/10PLC_With_10xFilter_01.JPG

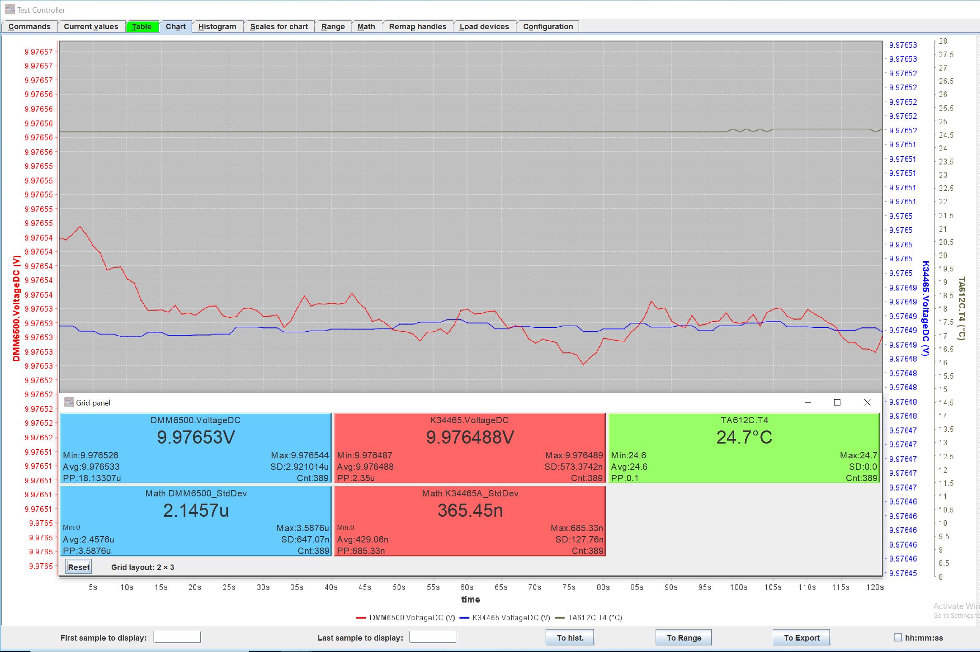
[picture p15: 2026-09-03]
uDR1399 Validation Tests/2min Tests/100PLC/100PLC_04.JPG

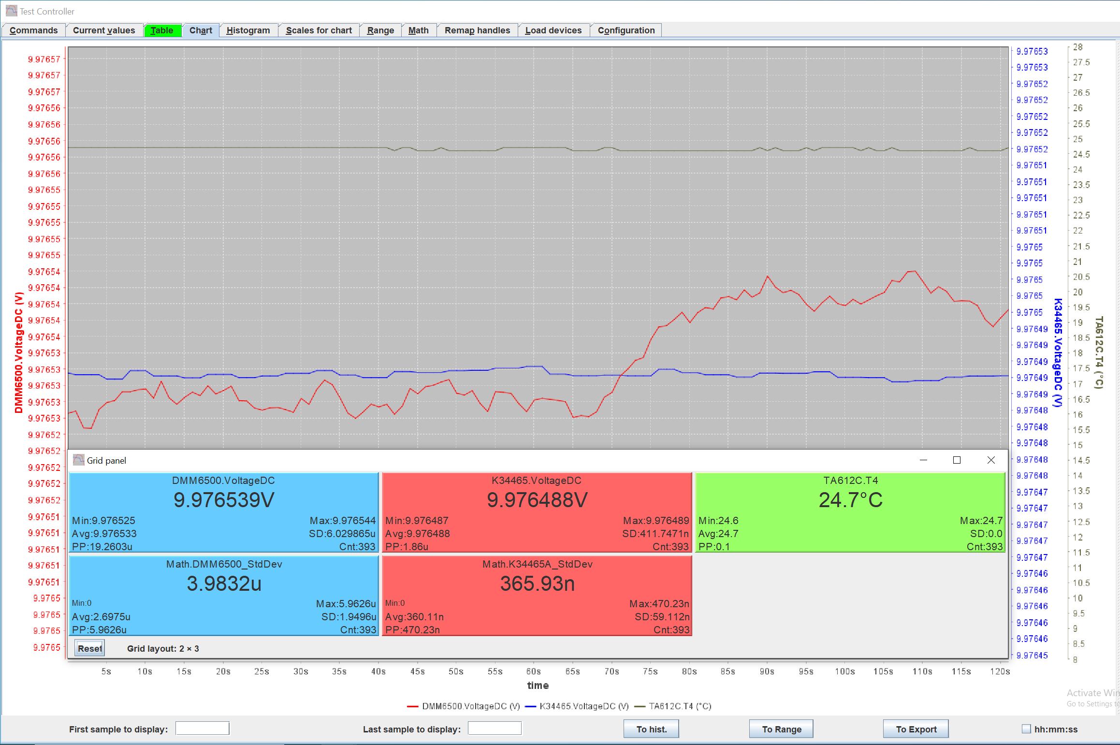
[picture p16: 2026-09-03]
uDR1399 Validation Tests/2min Tests/100PLC/100PLC_03.JPG

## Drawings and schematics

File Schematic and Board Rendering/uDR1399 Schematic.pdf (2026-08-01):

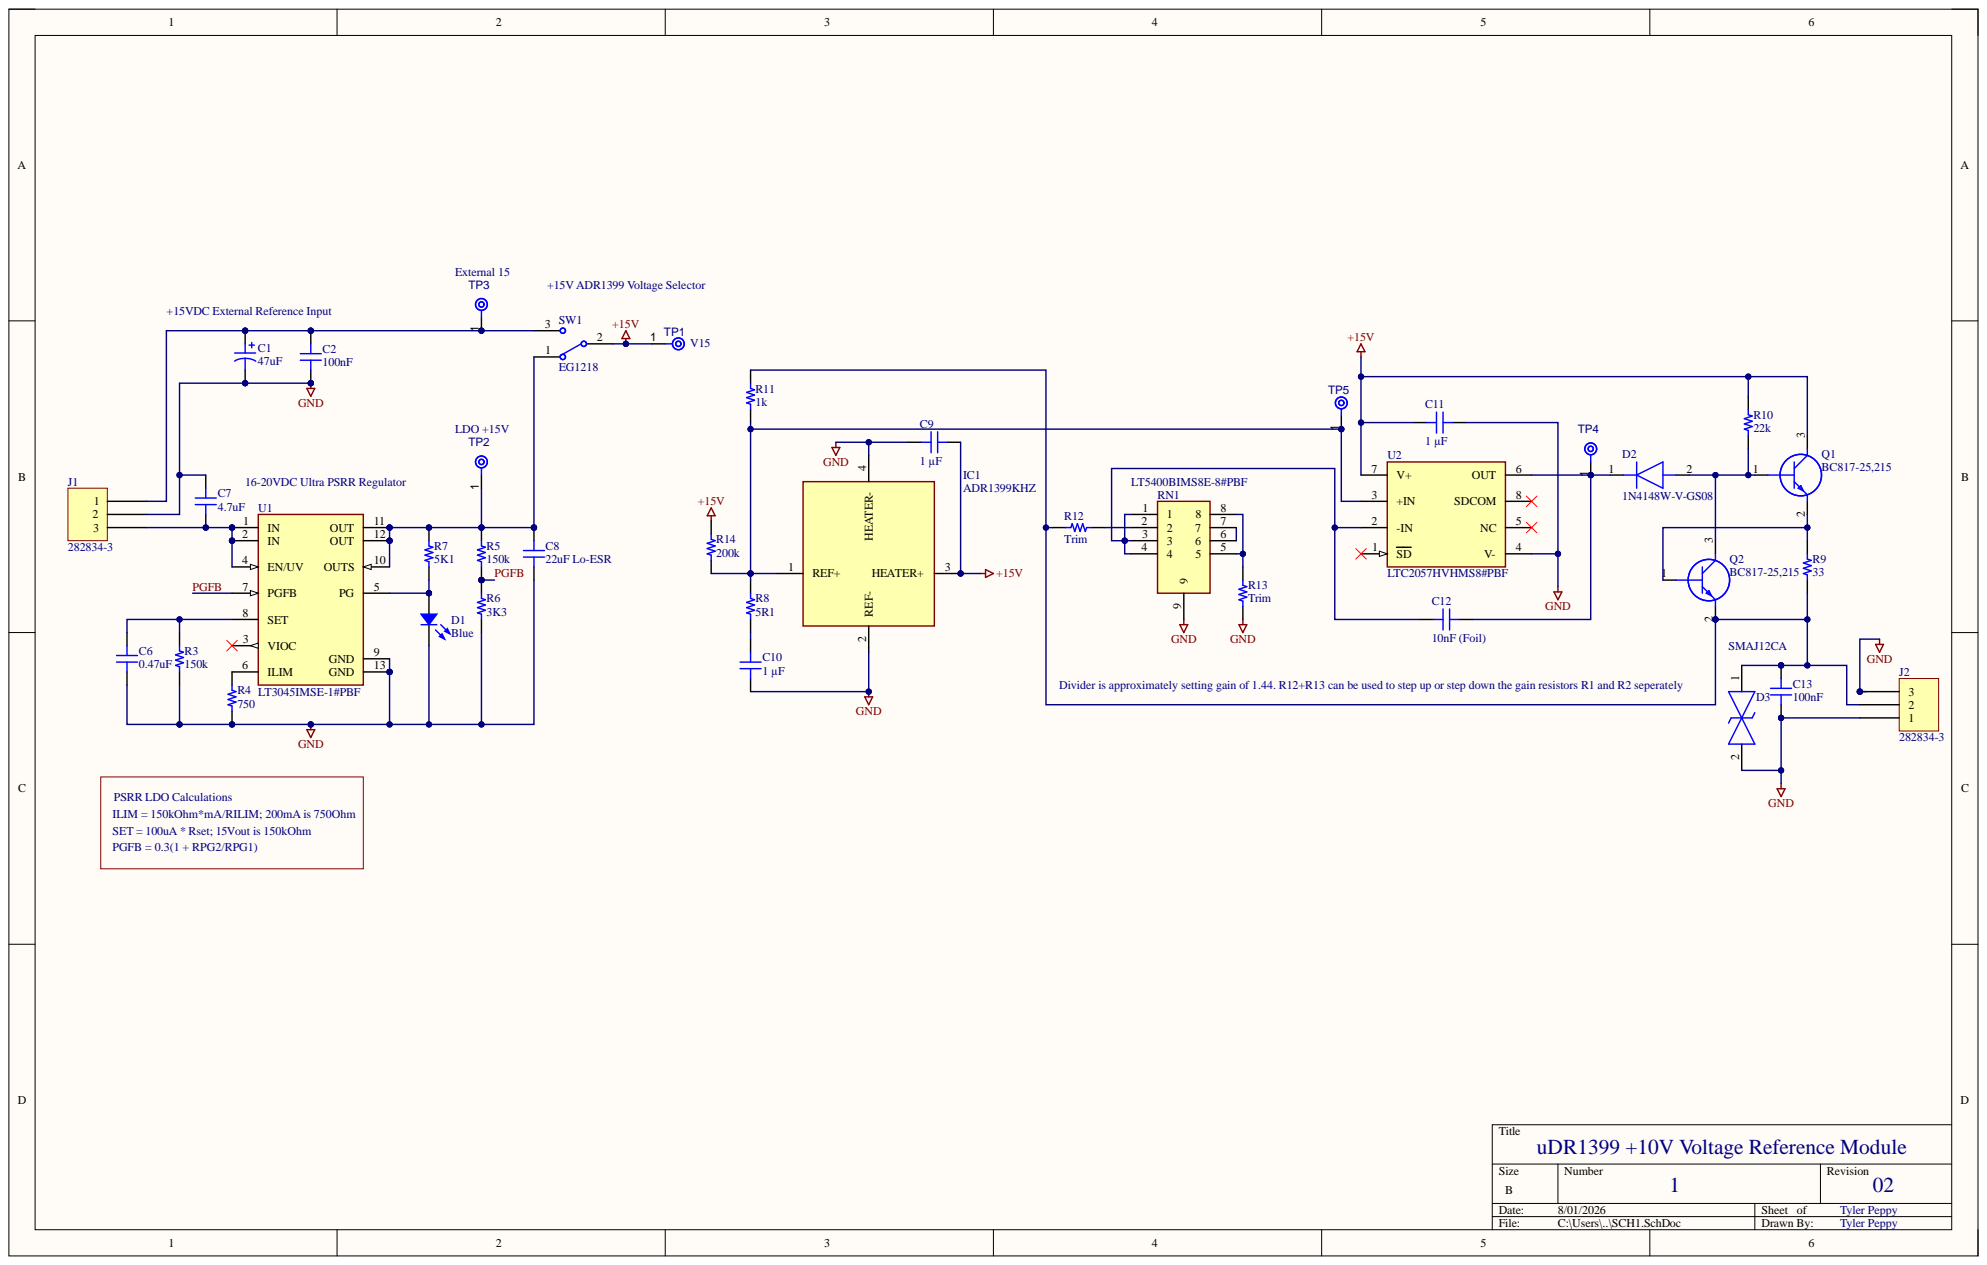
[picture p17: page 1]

Divider is approximately setting gain of 1.44. R12+R13 can be used to step up or step down the gain resistors R1 and R2 seperately

PSRR LDO Calculations
ILIM = 150kOhm*mA/RILIM; 200mA is 750Ohm
SET = 100uA * Rset; 15Vout is 150kOhm
PGFB = 0.3(1 + RPG2/RPG1)

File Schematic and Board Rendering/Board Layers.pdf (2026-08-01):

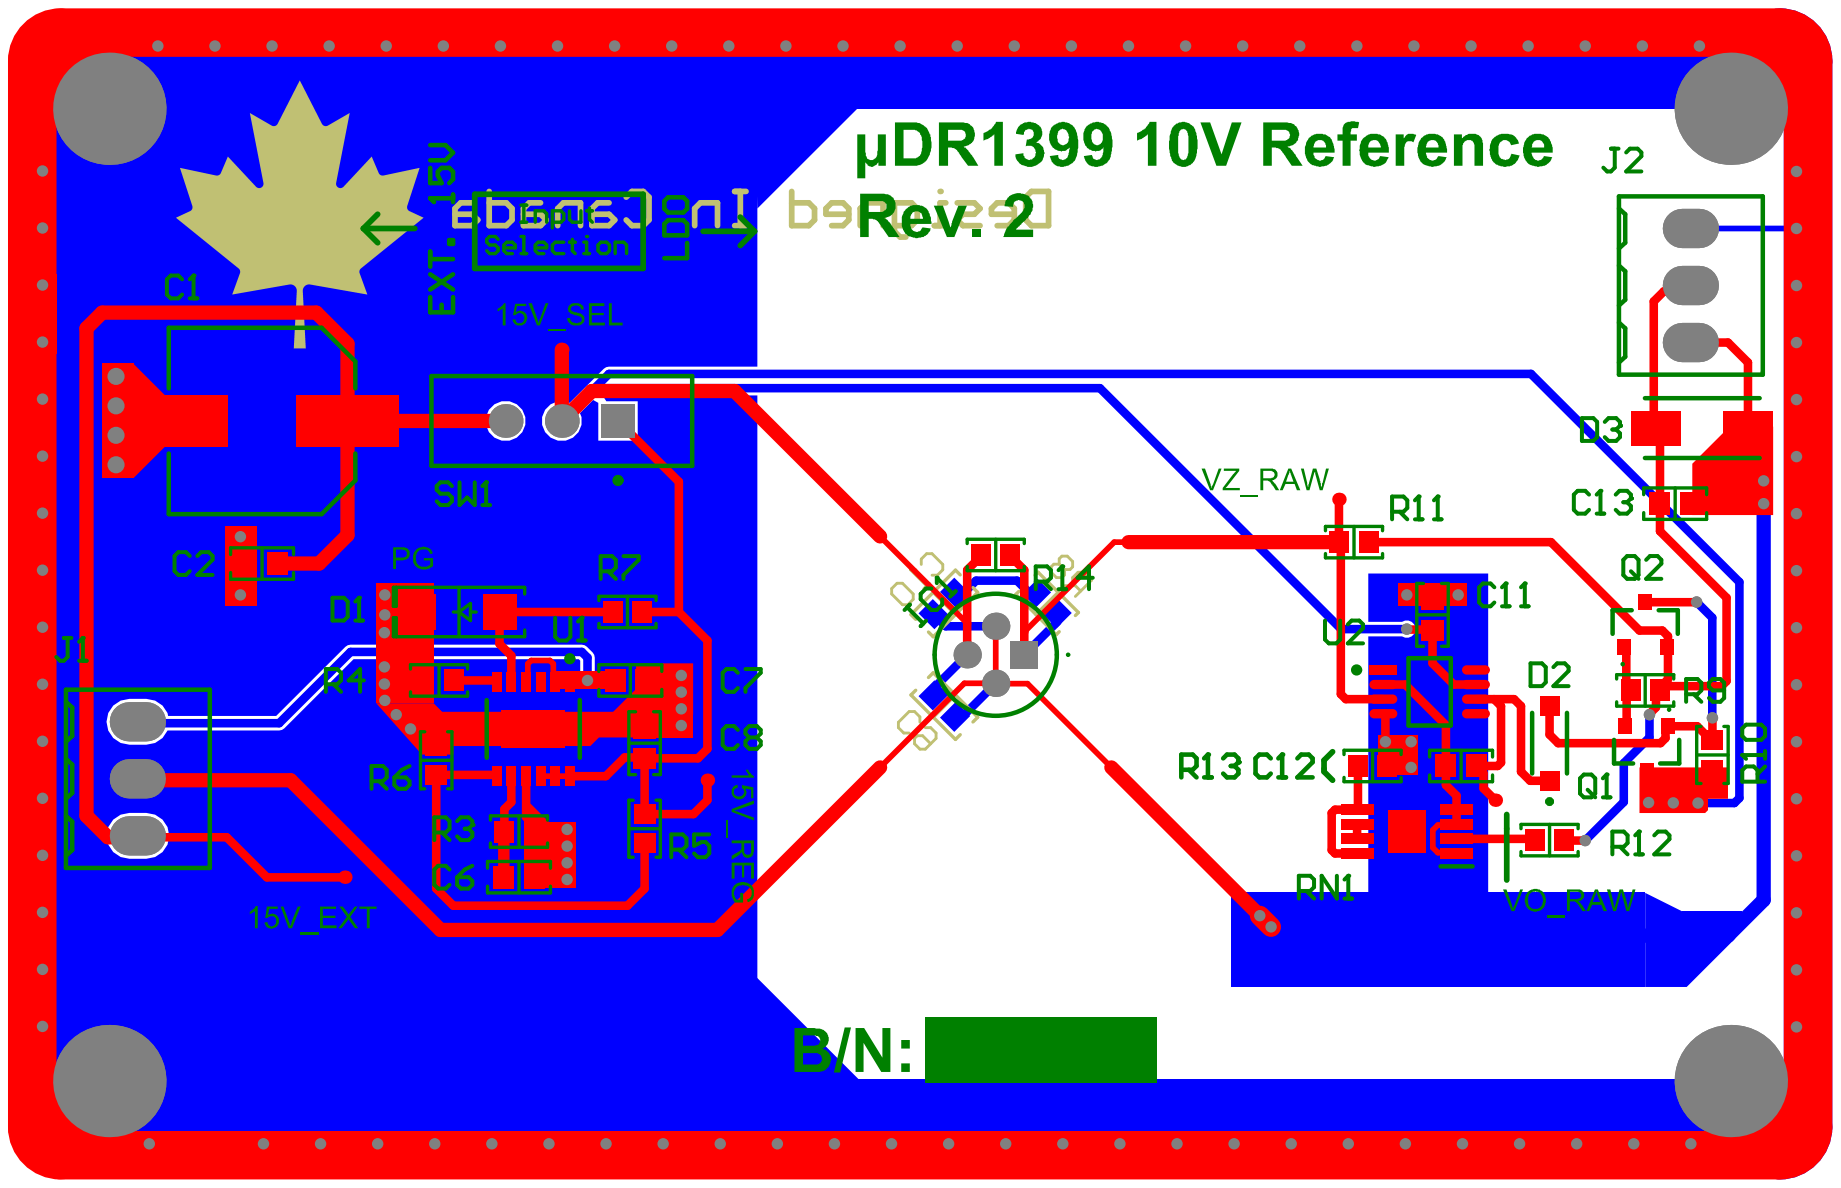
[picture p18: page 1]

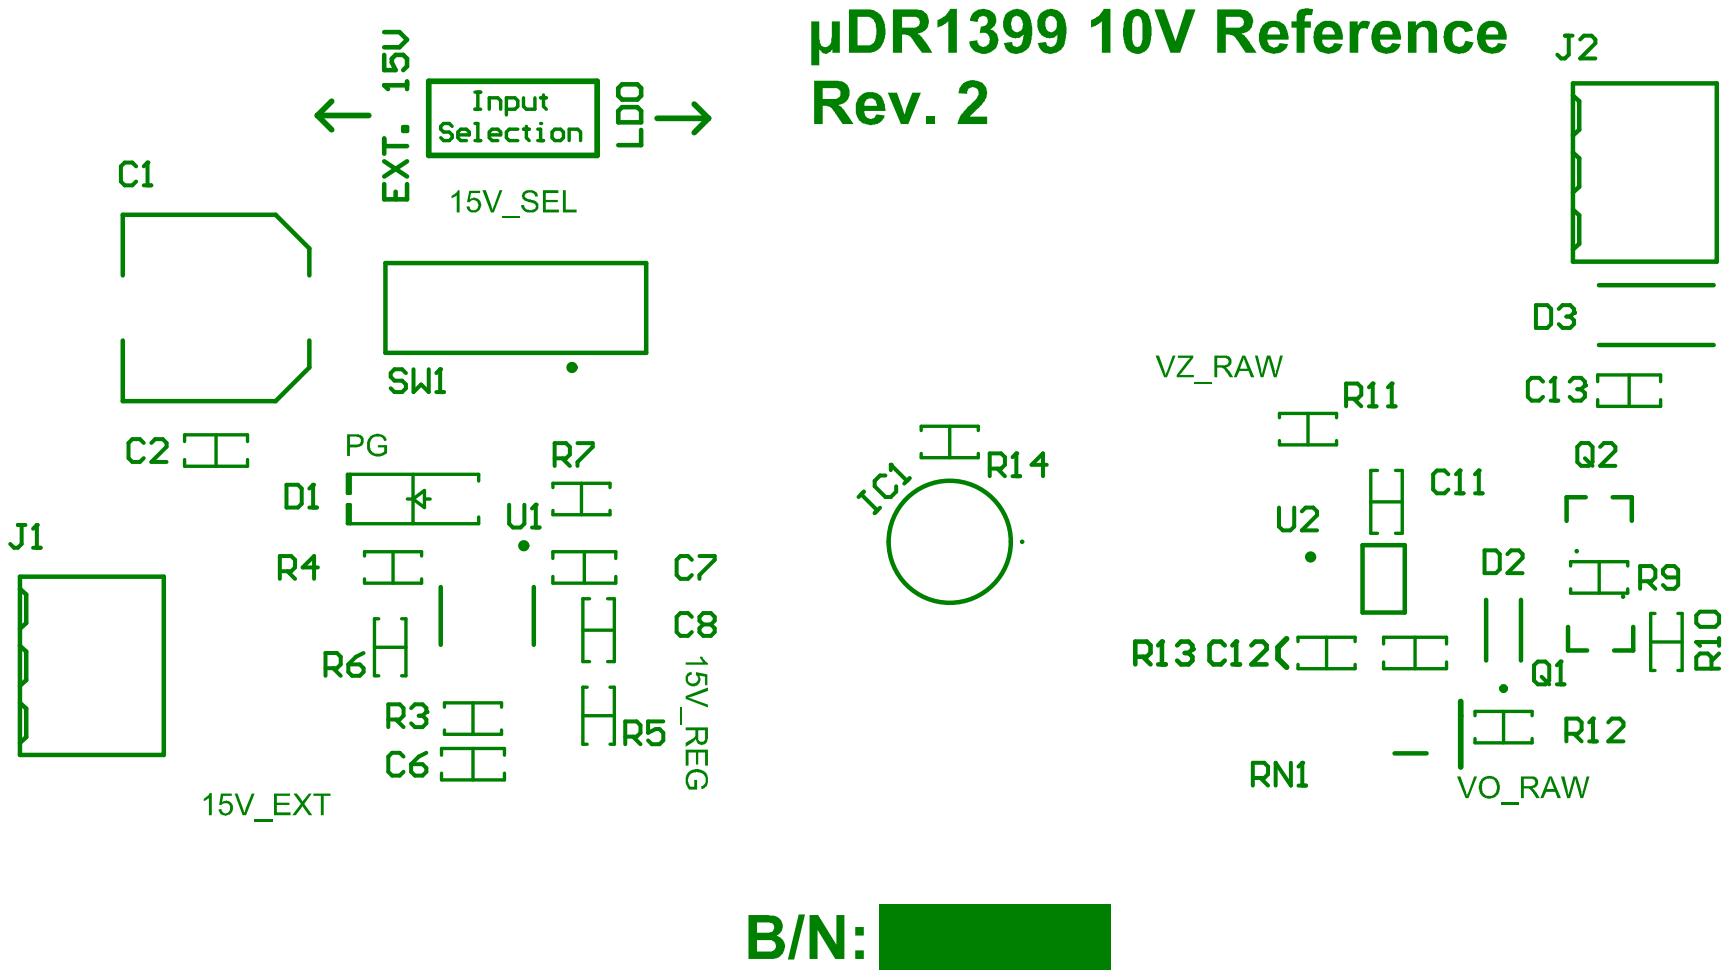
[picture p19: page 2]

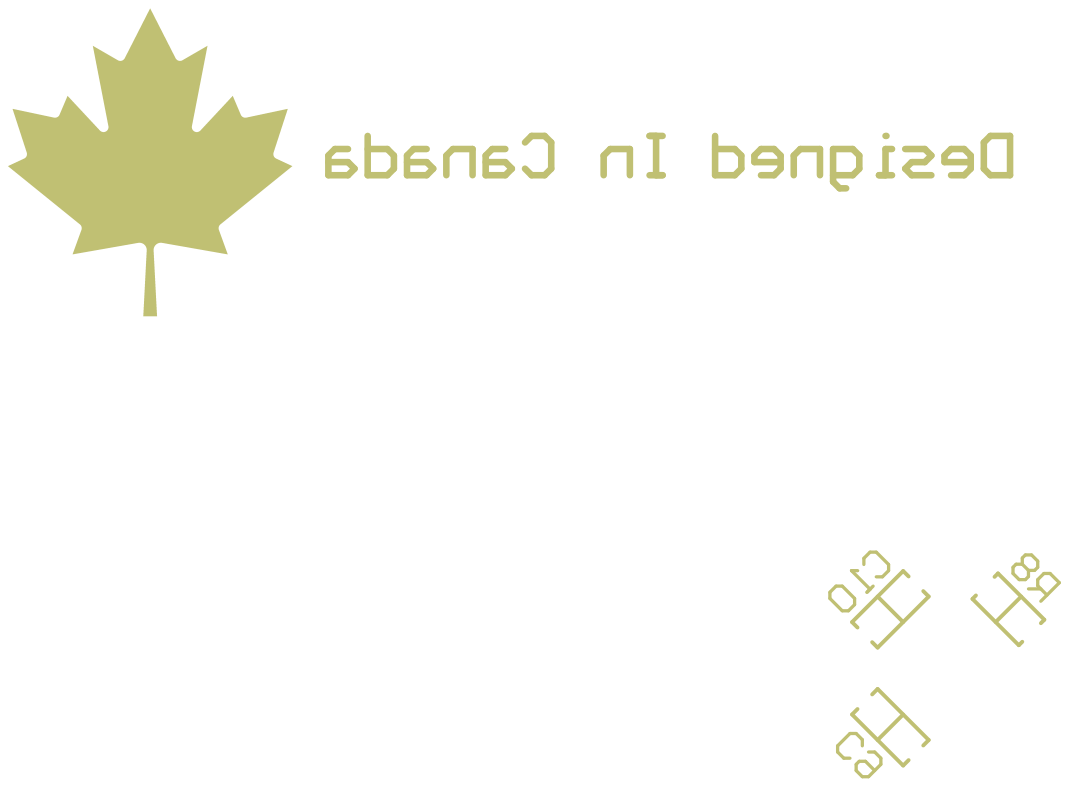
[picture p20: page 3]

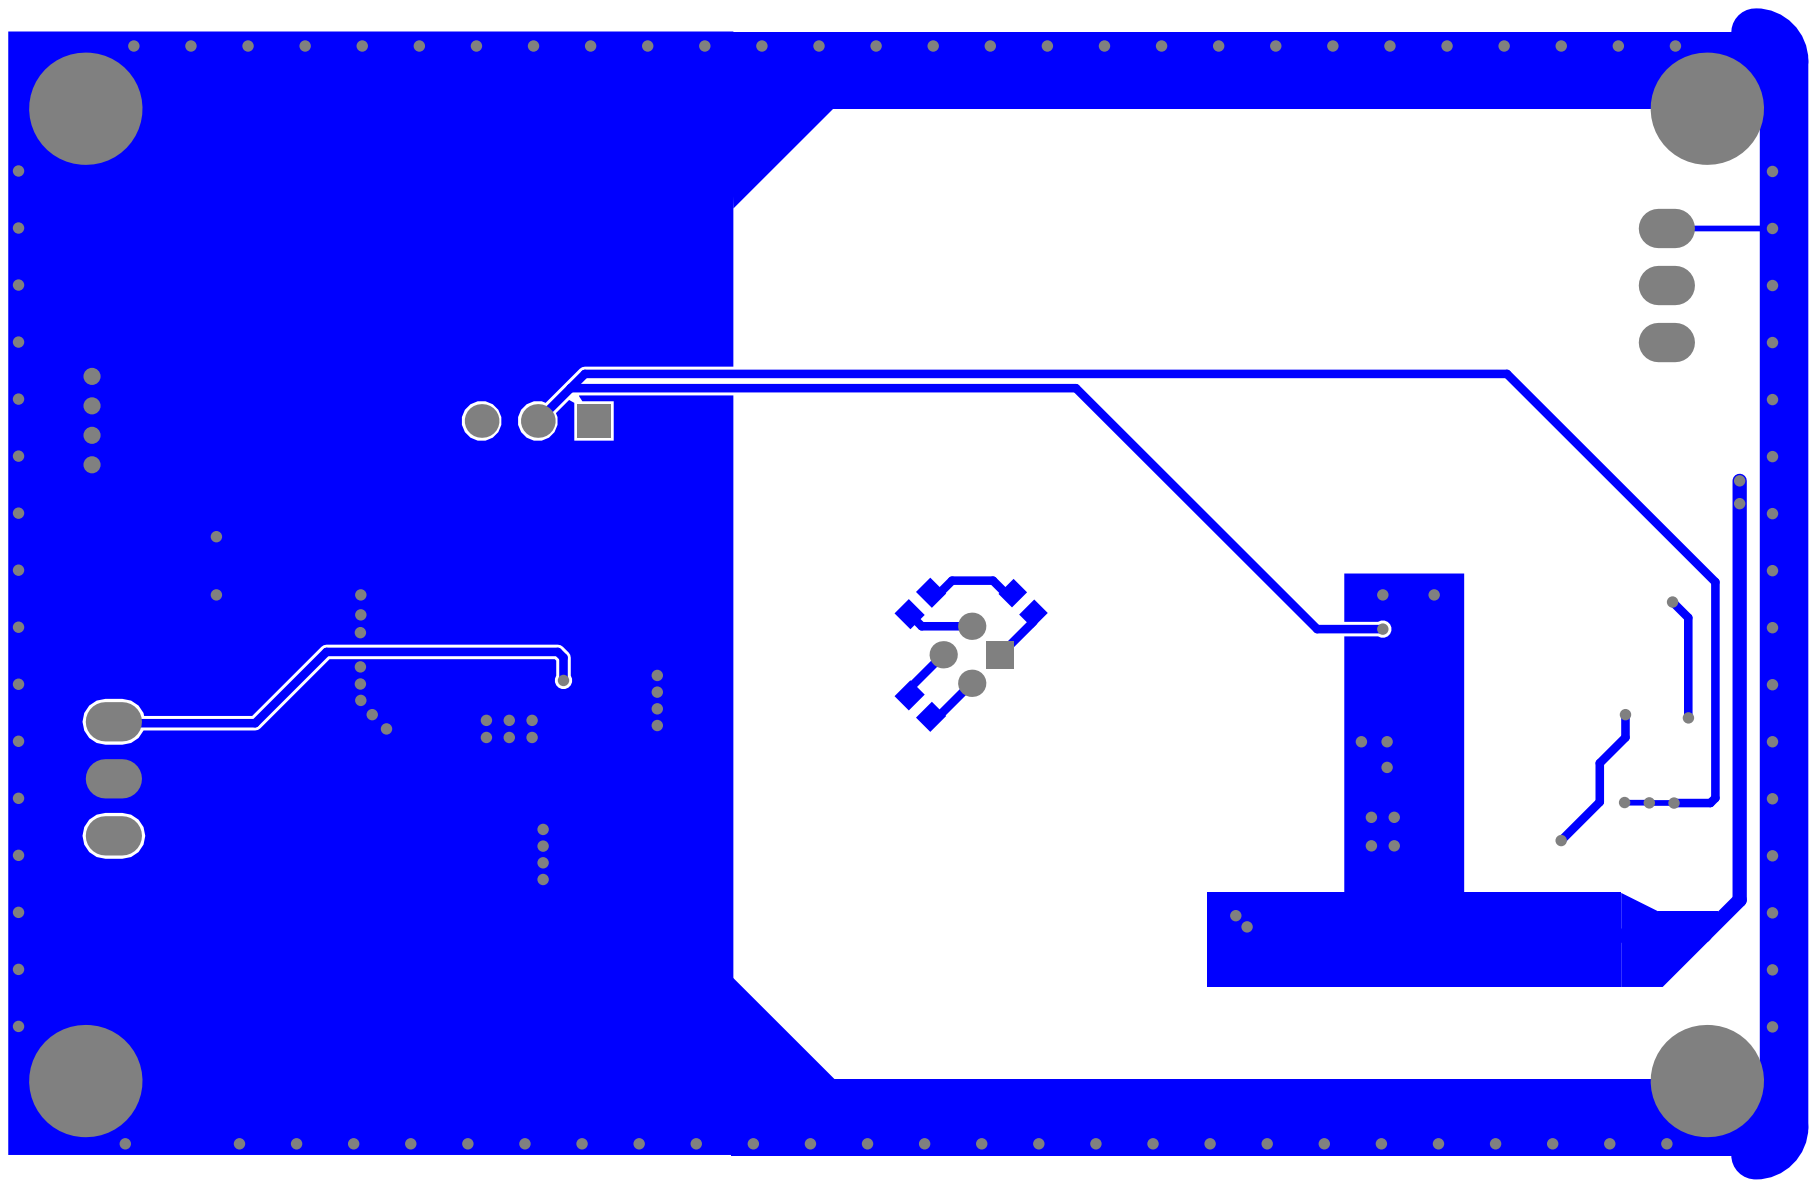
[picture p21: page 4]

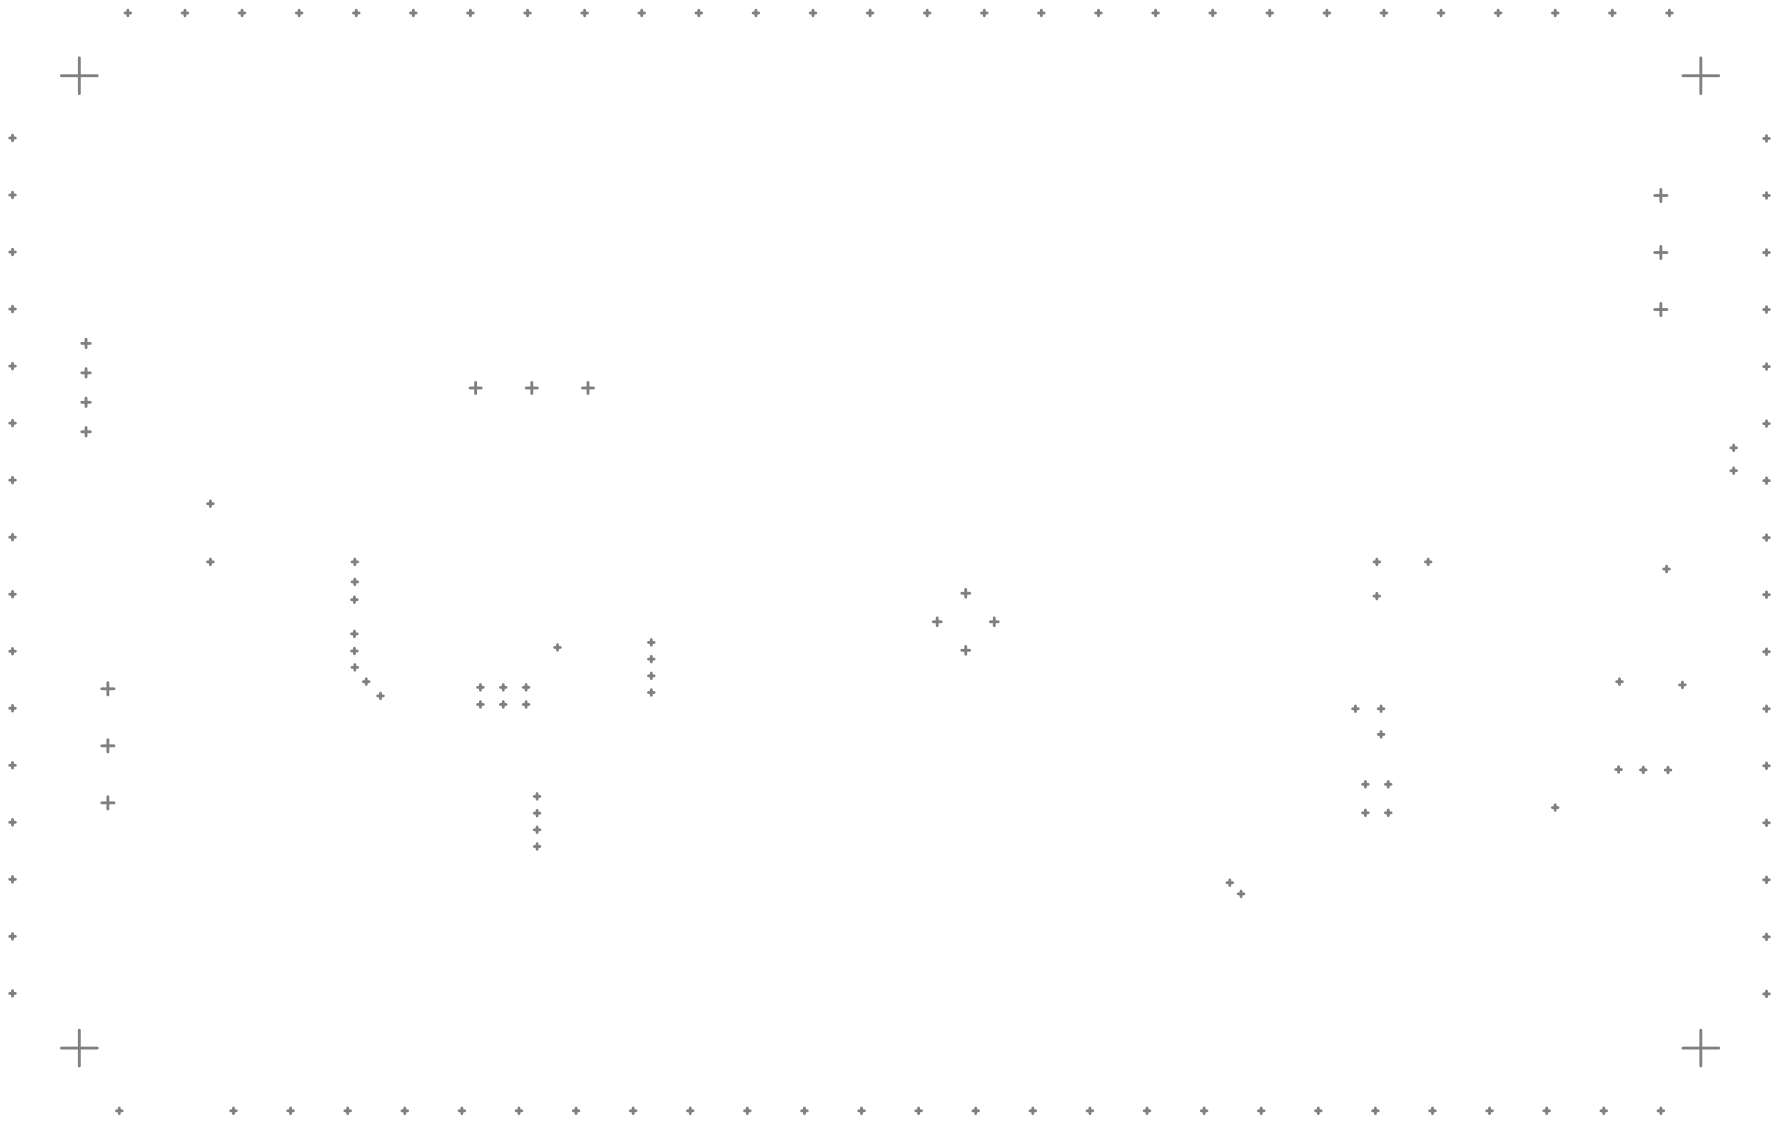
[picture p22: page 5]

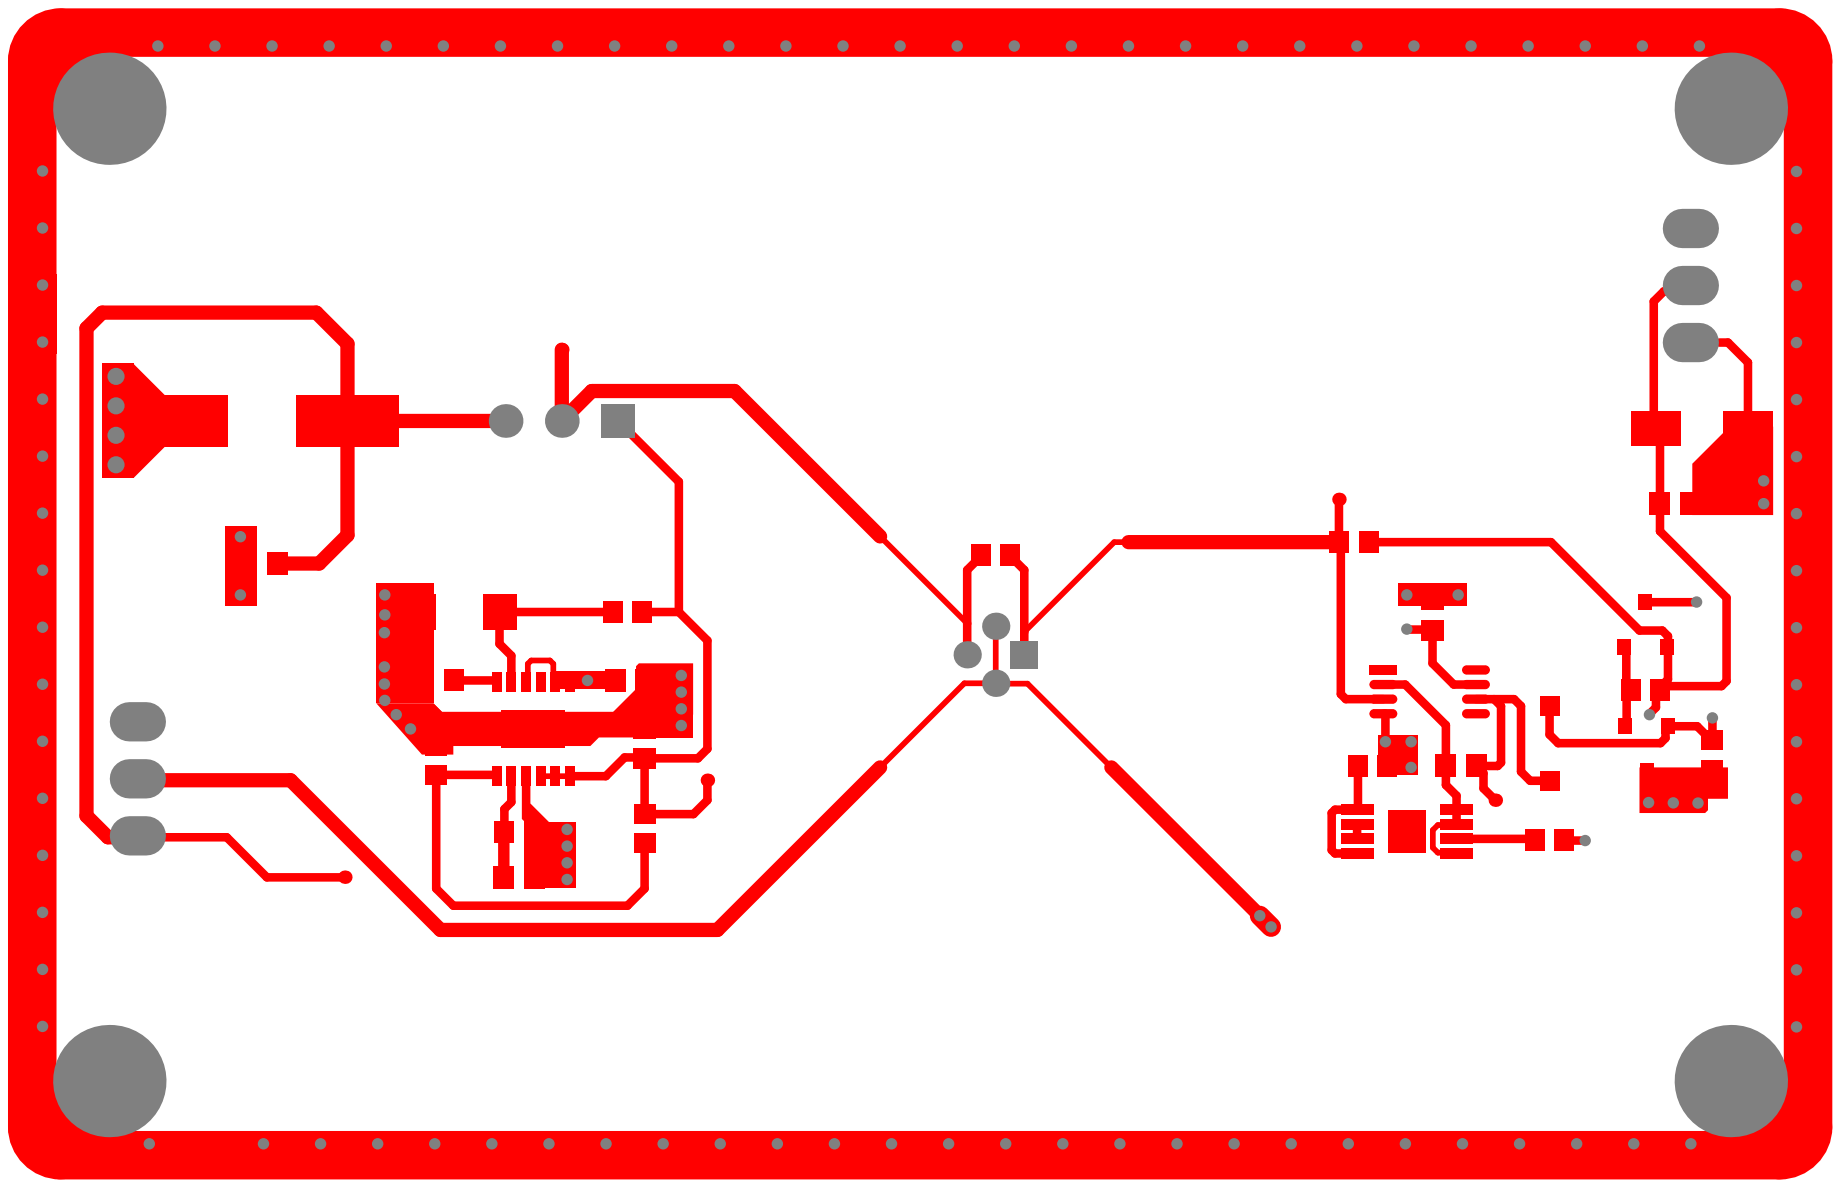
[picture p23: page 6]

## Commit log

2026-08-01 Update Files
    Added images and and initial design files
    [10V Reference Assembly.step, uDR1399 Board BOM.xlsx, uDR1399_Board_Model.step]
2026-08-01 Create schematiccapture.png
    Push new schmatic screenshot
